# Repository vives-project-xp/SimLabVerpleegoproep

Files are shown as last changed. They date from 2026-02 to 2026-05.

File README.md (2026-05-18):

# SimLab Verpleegoproepsysteem

## Projectbeschrijving

Het doel van dit project is om een systeem te ontwikkelen die hulpverlenend personeel help om visueel te zien welke patiënten zorg nodig hebben en waar collega’s al bezig zijn. Het systeem werkt met drukknoppen en signalisatie lampen zodat de status van de kamer kan weergegeven worden. Wanneer de patiënt urgente hulp nodig geeft, krijg het personeel hiervan ook een melding op hun telefoon.

Dit project zal dan ook werkelijk gebruikt worden door de graduaat en bachelor opleidingen verpleegkunde als lesmateriaal.

## Functies/onderdelen

- **Drukknop aan bed:** gebruikt door patiënt om hulp op te roepen.
- **Drukknop aan muur:** gebruikt door hulpverlener om aanwezigheid te registreren en lamp uit te schakelen.
- **Signaallamp aan muur of deur:** geeft visueel de status van de kamer weer.
- **Telefoon hulpverlener:** krijgt melding wanneer hulp urgent is.

## Optionele uitbreidingen
Dit zijn uitbreidingen die mogelijk zijn als we genoeg tijd over hebben, de basis functionaliteiten moeten eerst werkend zijn.

- **Applicatie met status:** kan gebruikt worden om weer te geven welke status de geregistreerde kamers hebben.
- **Batterij status:** de status van de batterij wordt weergegeven op een applicatie, op deze manier weten we wanneer de batterij moet opgeladen worden.

## Affiches

### Begin affiche

<div style="display: flex; gap: 10px;">
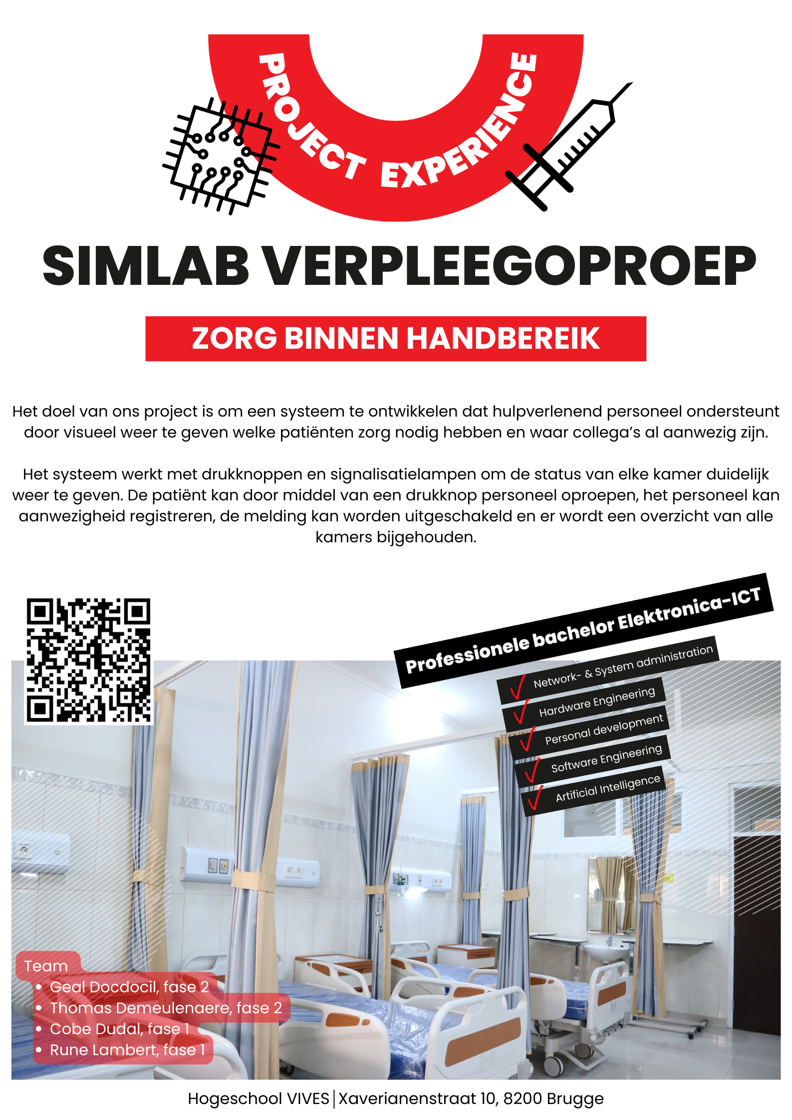
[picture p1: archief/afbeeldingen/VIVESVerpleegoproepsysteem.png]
   
</div>

### Eind affiche

<div style="display: flex; gap: 10px;">
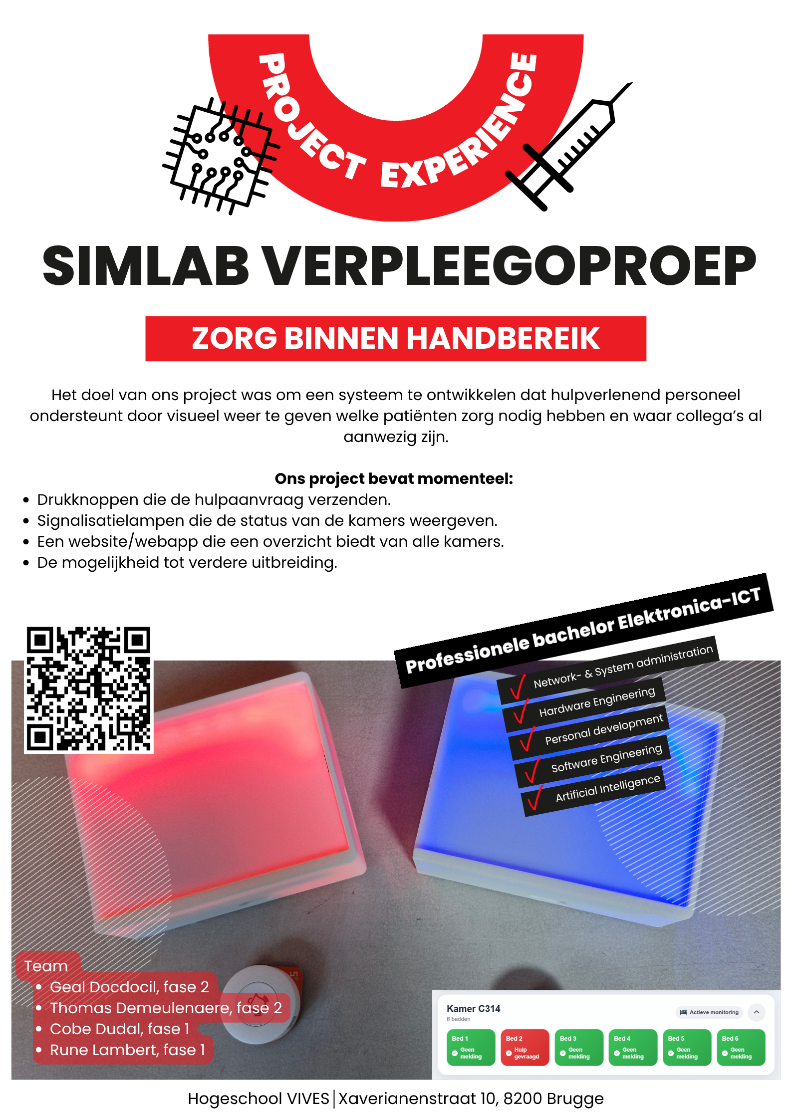
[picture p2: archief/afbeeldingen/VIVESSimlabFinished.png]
   
</div>

## Folder structuur
- [Hardware](./hardware/readme.md) : Hier bevind alles te maken met de hardware.
- [Software](./software/readme.md ) : Hier bevind alles te maken met de software.
- [Archief](./archief/readme.md) : Hier vindt u moglijke ideeën en bestanden die gebruikt worden in de documentatie.
- [Research](./Research/readme.md) : Hier vindt u het onderzoek in verband met het project.

## Team
- [Foto Thomas Demeulenaere, fase 2](https://github.com/Thomas8650)

- [Foto Geal Docdocil, fase 2](https://github.com/Gdoc141)

- [Foto Cobe Dudal, fase 1](https://github.com/ToneyBacon)

- [Foto Rune Lambert, fase 1](https://github.com/RuneLambert)

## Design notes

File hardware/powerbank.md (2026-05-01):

# **Specificaties en gegevens powerbank**

# Inleiding

In dit bestand zullen de specificaties en gegevens van de powerbank terug te vinden zijn.

## Gegevens

| Soortnaam | Laaduitgangen en -schachten |  Capaciteit (mAh, Ah) | Laadstroom (max.) | Technologie |
|--|--|--|--|--|
| Powerbank | 2 | 10000 mAh | 3100 mA | LiPo |

| Lengte | Breedte | Hoogte | Gewicht |
|--|--|--|--|
| 91 mm | 63 mm| 22 mm| 182 g|

| Kleur (specifiek) | Draadloos oplaadbaar | Afm. |
|--|--|--|
| Zwart | Nee| (l x b x h) 91 x 63 x 22 mm|

| Aansluitingen | 1x USB-C | Kenmerken powerbank |
|--|--|--|
| 1x USB-A | 1x USB-micro| Statusweergave|

| USB-C uitgangsspanning (max.) | USB-C uitgangsstroom (max.) | USB-C ingangsspanning (max.) | USB-C ingangsstroom (max.) | Grootte |
|--|--|--|--|--|
| 5 V| 3.1 A| 5 V| 2.4 A| AAA (potlood)|

## Duur bij max. belasting

Uit de gegevens van de powerbank kunnen we afleiden hoelang deze kan gebruikt worden met een max. belasting.
We kunnen afleiden dat een volledig opgeladen powerbank voor ongeveer 53,8 min een volle belasting van 5 V en 3,1 A kan voorzien.

In realiteit zal de powerbank nooit deze grote waarden moeten leveren en voor een constante periode. De powerbank zal niet altijd aan zijn. Indien deze toch aan is zullen de LED's niet altijd branden en de getrokken stroom nooit 3,1 A bereiken.

Dit betekend dat de daadwerkelijke levensduur van een volledig opgeladen powerbank stukken groter zal zijn dan deze 53,8 min.

Als we een ruim gerekende stroom van ongeveer 500 mA nemen, resulteerd dit in een levensduur van ongeveer 20 h. Deze 20 h is dan ook voor constante belasting, in realiteit zullen de LED's niet altijd aan liggen en ook niet met volle sterkte branden. Als we met een factor 3 (LED's branden niet altijd en worden niet altijd gebruikt) rekening houden hebben we een levensduur van 60 h, deze waarde kan in realiteit nog hoger liggen aangezien de gebruikte waarden nog altijd ruim gerekend zijn.

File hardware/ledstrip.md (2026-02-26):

# Informatie LED strip

## Belangrijke gegevens

**Naam:** PN.:HC-F5V-60L-60LED-W-WS2812B

**Lengte:** 1 meter

**Werk spanning:** DC5V

**Max. vermogen:** 9W

**Verpakking:** Bare Board

**Werkmodus:** external controller

## Aansluitingen
**JST-SM stekker (3-pin):** 
 - Rood: VCC
 - Wit: GND
 - Groen: DAT

**2 apparte kabels:** 
 - Rood: +5V
- Zwart: GND

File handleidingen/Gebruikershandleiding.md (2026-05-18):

# Gebruikershandleiding

## Inhoudstafel 
[**Inleiding**](#inleiding)<br>
[**Installatie systemen**](#installatie)<br>
- [**Installatie knop**](#knop)<br>
- [**Installatie applicatie**](#applicatie)<br>

[**Gebruik knop**](#gebruik-knop)<br>
[**Gebruik app/website**](#gebruik-app_website)<br>
[**Gebruik signalisatie lamp**](#gebruik-signalisatie-lamp)<br>
[**Onderhoud lamp en knop**](#onderhoud)<br>
[**FAQ**](#faq)<br>

## Inleiding
Dit bestand bevat een uitgebreide handleiding bestemd voor de gebruiker van het systeem, er zullen geen technische details of diepgang voorkomen. Er zal gesproken worden over de installatie, gebruik, onderhoud en FAQ.

## Installatie
### **Knop**
De knop installeren gebeurt heel eenvoudig.
1.	Steek de knophouder in het gat van de oranje schijf.

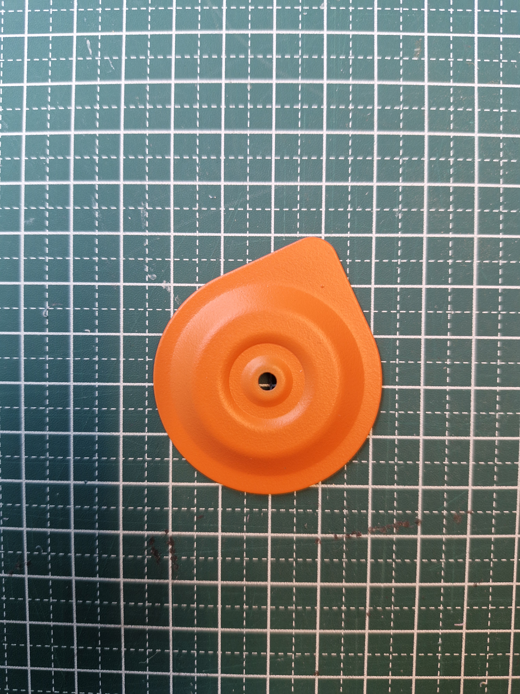
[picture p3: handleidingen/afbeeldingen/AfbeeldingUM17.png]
<br>

2.	Klik de knop op de schijf met behulp van de ingebouwde magneet.
3.	Schuif de knophouder over de afstandsbediening van het bed of over andere passende objecten, er kan ook gebruik gemaakt worden van een koord.
4.	De knop zou standaard al in het systeem moeten zitten waardoor deze meteen bruikbaar zou moeten zijn, indien dit niet gebeurt druk dan kort op de kleine pairing knop aan de zijkant van de knop zelf.

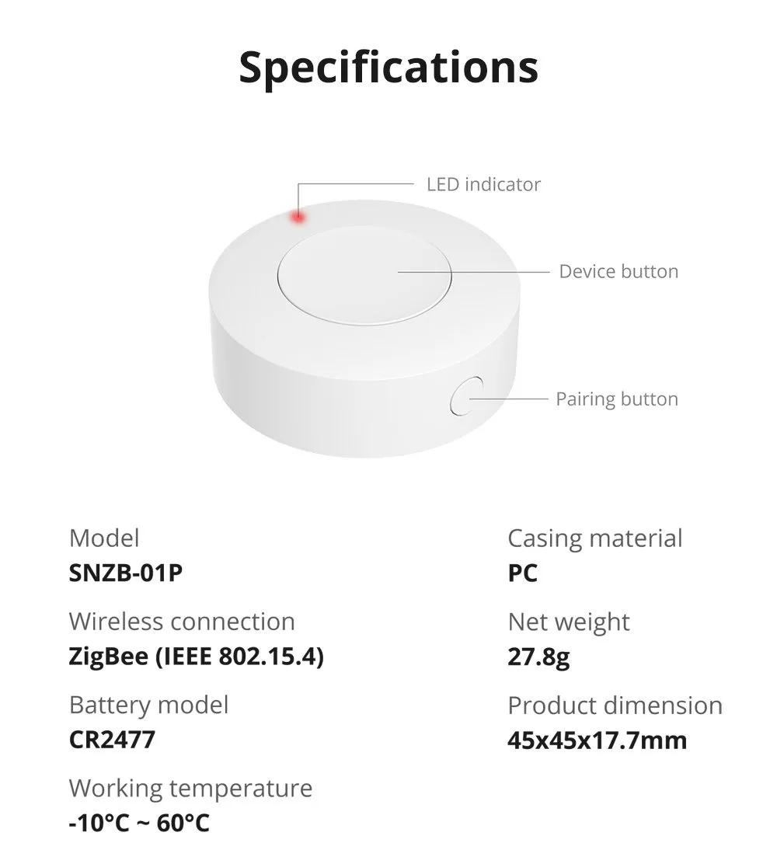
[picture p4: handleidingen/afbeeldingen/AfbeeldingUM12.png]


### **Applicatie**
De volledige installatiehandleiding voor de applicatie (voor zowel iPhone als Android) is terug te vinden in de [PWA-Installatiehandleiding](PWA-Installatiehandleiding.md).

## Gebruik knop
Bij iedere melding of verandering in de app, krijgt iedere medewerker (docent en student) die op dat moment zijn ingelogd en meldingen ingeschakeld heeft een bijhorende melding.

### **Meldingen patiënt**
#### **Hulp gevraagd**
Wanneer de patiënt hulp nodig heeft drukt deze **1x kort** op de knop.

Dit zorgt ervoor dat het bijhorende bed op de app rood kleurt, deze als “Hulp gevraagd” geregistreerd wordt en indien er geen belangrijkere meldingen zijn zal de lamp van de kamer rood kleuren.

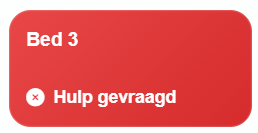
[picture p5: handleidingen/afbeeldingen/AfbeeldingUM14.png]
<br>

### **Personeel (medewerker)**
#### **Aanwezigheid registreren**
Als de medewerker aanwezigheid wilt registreren wanneer er voordien hulp gevraagd werd, kan dit door **2x kort na elkaar** op de knop te drukken waar de melding vandaan kwam.

Dit zorgt ervoor dat het bijhorende bed op de app van rood naar oranje kleuren, deze als “Collega aanwezig” geregistreerd wordt en indien er geen belangrijkere meldingen zijn zal de lamp van de kamer oranje kleuren.

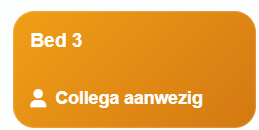
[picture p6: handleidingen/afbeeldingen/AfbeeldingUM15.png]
<br>

#### **Uitschakelen**
Als de medewerker de melding wilt afhandelen of uitschakelen kan dit door **1x kort** op de bijhorende knop te drukken (enkel als deze al brand anders wordt er om hulp gevraagd).

Hierdoor zal het bijhorende bed op de app terug groen kleuren en de lamp van de bijhorende kamer uitgeschakeld worden indien er geen andere meldingen zijn.

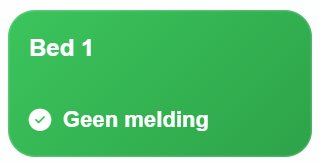
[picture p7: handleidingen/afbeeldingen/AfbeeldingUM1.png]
<br>

#### **Extra hulp nodig**
Als de medewerker **1x lang** de knop indrukt (ongeveer 2s-3s), zal er een extra hulp aanvraag verzonden worden.
Ook als er meer dan één "Hulp gevraagd" meldingen in dezelfde een kamer zijn zal automatisch extra hulp opgeroepen worden.

Dit zorgt ervoor dat het bijhorende bed op de app blauw brand, deze als “Extra hulp nodig” geregistreerd wordt en de lamp van de bijhorende kamer blauw kleurt.

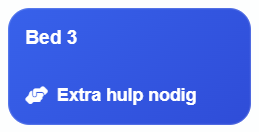
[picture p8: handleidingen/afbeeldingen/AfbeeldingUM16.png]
<br>

**Instructieblad:**

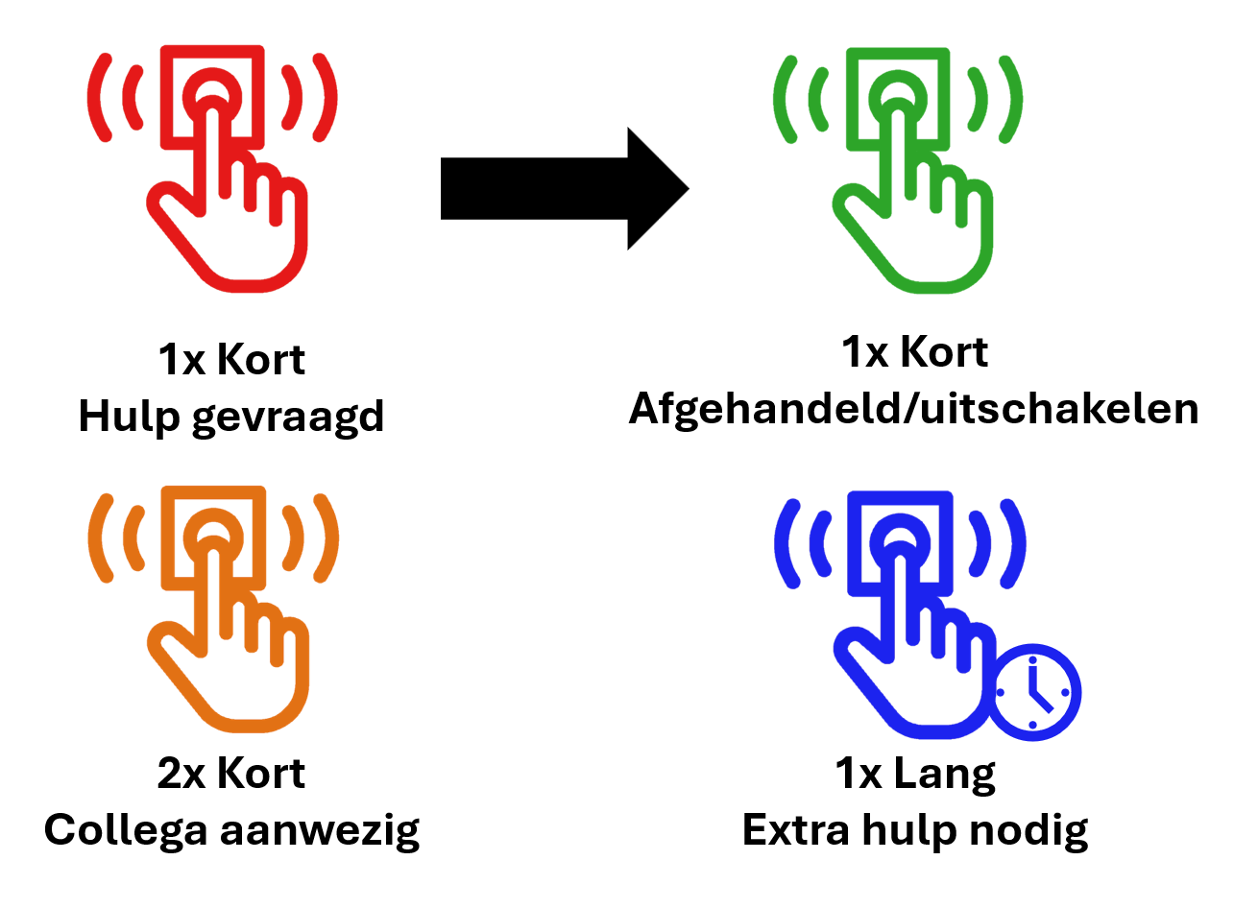
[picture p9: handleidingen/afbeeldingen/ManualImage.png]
<br>

## Gebruik app_website
Bij ons systeem hoort een website en een app die een overzicht geven van de meldingen, status van kamers met bedden en het mogelijk maakt om meldingen te ontvangen.
Bij iedere melding of verandering in de app, krijgt iedere medewerker (docent en student) die op dat moment zijn ingelogd een bijhorende melding.
### **Inloggen**
Als u surft naar https://verpleegkunde.voltlab.net of de applicatie opent komt u op onderstaand scherm terecht.
 
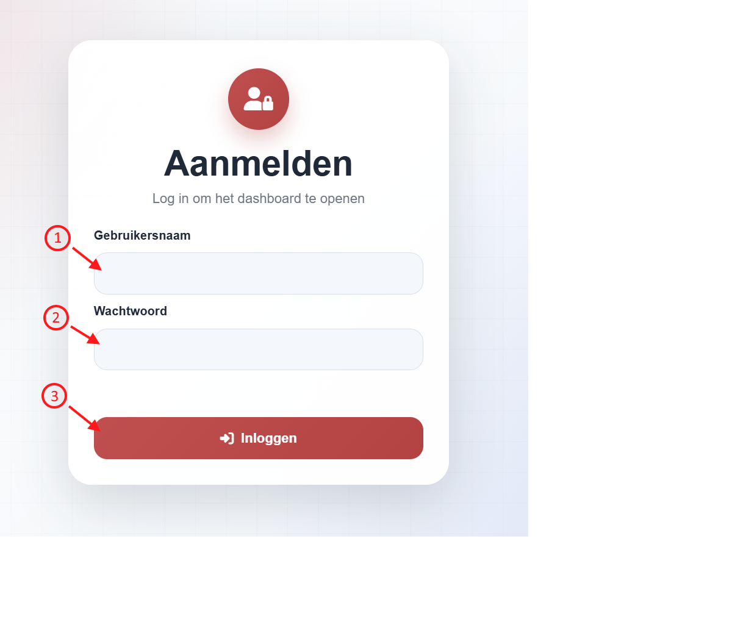
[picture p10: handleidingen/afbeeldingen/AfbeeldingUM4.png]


1.  In het vak “Gebruikersnaam” vult u een bestaande gebruikersnaam in. Indien u een leerling bent vult u “Leerling” in, indien u een leerkracht bent vult u “Leerkracht” in.

2.  In het vak “Wachtwoord” vult u een correct wachtwoord in. Indien u een leerling bent krijgt u deze van uw leerkracht.

3.  Wanneer alles ingevuld is mag op de “Inloggen” knop gedrukt worden.<br>
**OPGELET: Het inloggen is hoofdletter gevoelig.**

### **Overzicht (leerling)**
Wanneer u ingelogd bent als leerling krijgt u onderstaand overzicht.

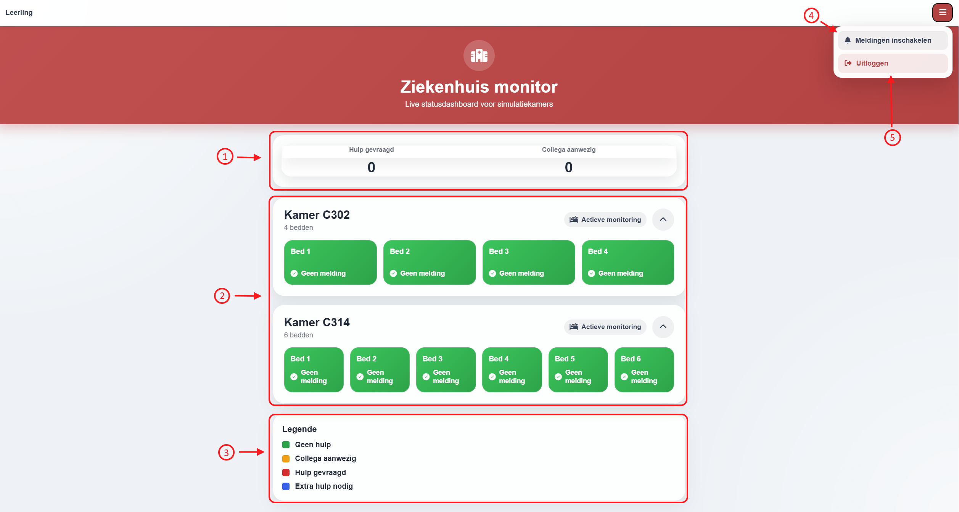
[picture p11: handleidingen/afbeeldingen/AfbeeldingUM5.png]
<br>
 
1.  **Overzicht aanvragen:** Hier is de totale som van alle aanvragen te zien. De hoeveelheid “Hulp gevraagd” en “Collega aanwezig” meldingen zijn hier terug te vinden.

2.  **Overzicht kamers:** Hier is een overzichtelijke weergave van de kamers terug te vinden. Per kamer en per bed zijn er vakken voorzien, deze veranderen van kleur en melding afhankelijk van het gebruik van de bijhorende knop. Op deze manier is alles makkelijk bij te houden.

3.  **Legende:** Een kleuren legende met informatie over de meldingen.

4.  **Meldingen inschakelen:** Deze knop moet ingedrukt worden om notificaties op een telefoon of andere toestellen te kunnen ontvangen.<br>
**OPGELET: Het is enkel mogelijk om notificaties te ontvangen met de applicatie niet met de website.**

1.  **Uitloggen:** Met deze knop kunt u uitloggen, na het uitloggen ontvangt u geen meldingen meer.

### **Overzicht (leerkracht)**
Het overzicht van een leerkracht is gelijkaardig aan dat van een leerling. Een leerkracht ziet wel de knop “Instellingen” staan onder de “Meldingen inschakelen” knop. Wanneer deze wordt ingedrukt komt u op het onderstaande menu terecht.

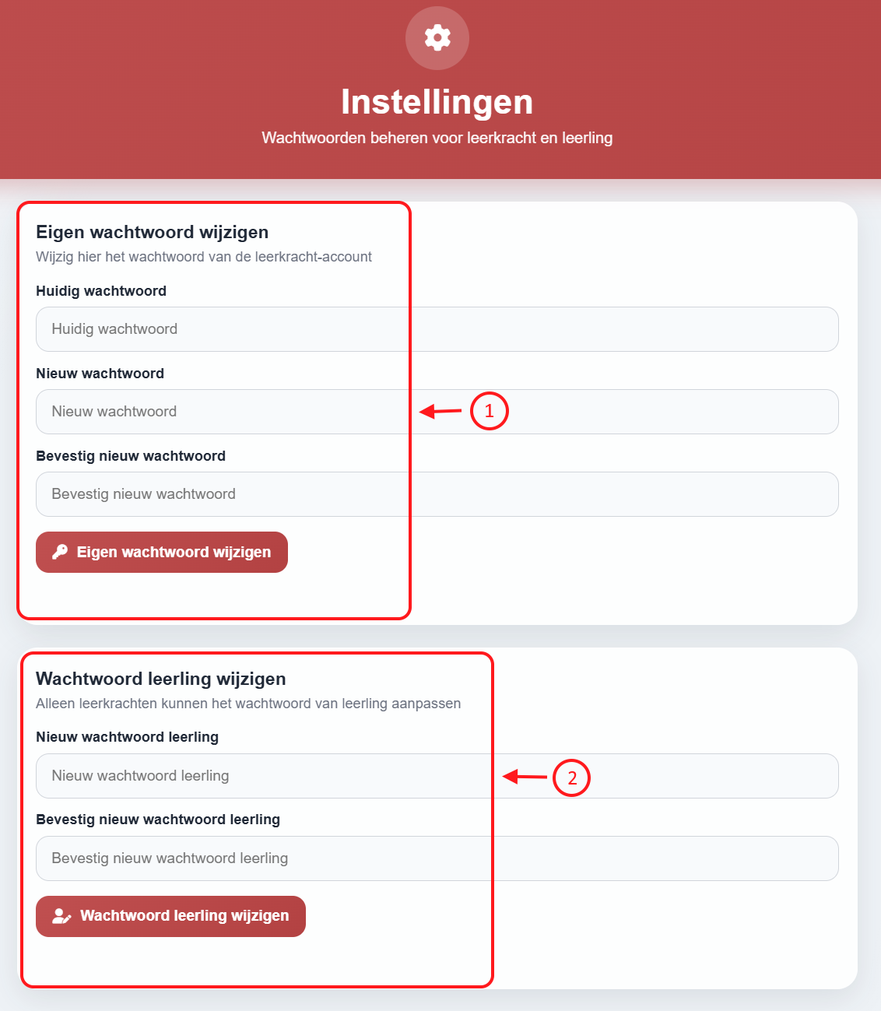
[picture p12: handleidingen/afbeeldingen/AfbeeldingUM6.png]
<br>
 
1.  In deze vakken kunt u het algemeen wachtwoord voor het leerkrachten account aanpassen. Dit gebeurt door eerst het huidige wachtwoord in te vullen en daarna twee keer het nieuwe wachtwoord.

2.  In deze vakken kunt u het algemeen wachtwoord voor het leerlingen account aanpassen. Dit gebeurt door twee keer het nieuwe wachtwoord in te vullen.<br>
**OPGELET: De wachtwoorden zijn hoofdletter gevoelig.**

## Gebruik signalisatie lamp  

### **Aanschakelen**
Het aanschakelen van de lamp gebeurt door 1x te drukken op de power knop van de powerbank. Deze knop kan eenvoudig bereikt worden door het gat in de behuizing.
Na het inschakelen zal de lamp voor 3s groen branden, dit betekend dat de lamp correct is ingeschakeld. Indien u niet zeker bent of de batterij ingeschakeld is, kunt u altijd het deksel er vanaf schuiven en controleren of de lichtjes van de powerbank effectief aan zijn.<br>
 
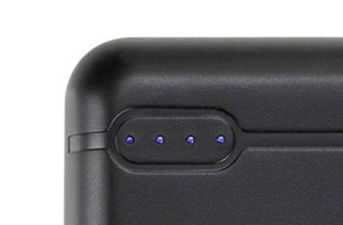
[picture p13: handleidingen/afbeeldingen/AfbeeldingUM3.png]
 

### **Uitschakelen**
Het uitschakelen van de lamp gebeurt door 2x kort achtereenvolgens op de power knop van de powerbank te drukken.

Wanneer de lamp geen veranderingen ontvangt voor een uur lang, zullen de batterij en lamp zich vanzelf uitschakelen.

Indien u niet zeker bent of de lamp ingeschakeld is, kunt u ook weer het deksel er vanaf schuiven en controleren of de lichtjes van de powerbank effectief uit zijn.<br>
 
 

## Onderhoud
### **Lamp**
Aangezien de lampen werken met een powerbank, moeten deze tijdig herladen worden.

1.  Verwijder de behuizing van de muur.

2.  Verwijder het schuivende deksel van de behuizing, nu zou de powerbank zichtbaar moeten zijn.

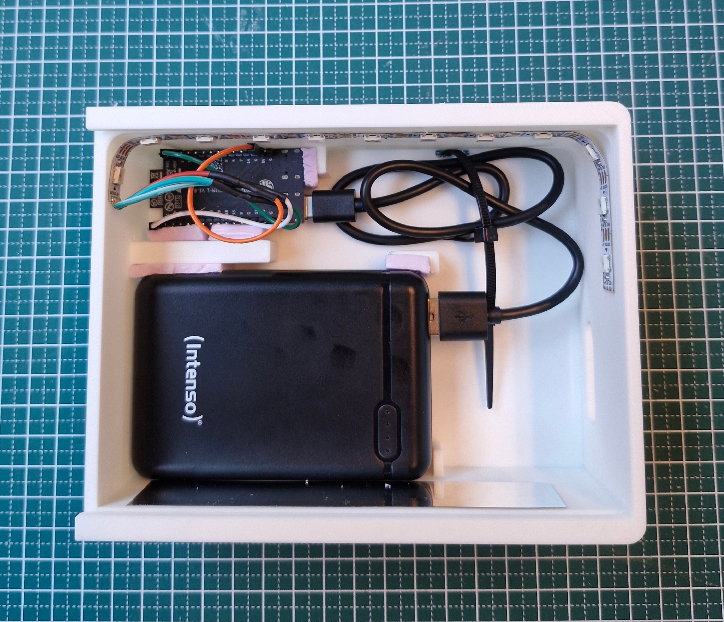
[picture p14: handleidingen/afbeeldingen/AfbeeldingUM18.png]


3.  Gebruik een USB-C kabel en steek deze in de correcte poort aangeduid op de powerbank als “USB-C In/Out”.

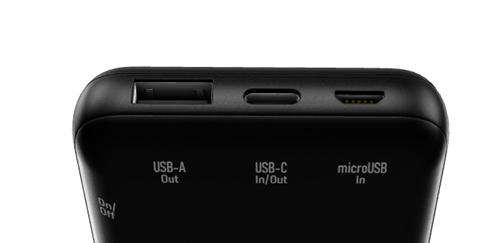
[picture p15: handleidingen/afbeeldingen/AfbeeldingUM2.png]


4.  Deze kabel kan nu gebruikt worden om de powerbank op te laden. U kunt de kabel makkelijker bereikbaar maken door deze door het voorziene gat in de behuizing te steken of u kunt gerust de powerbank uit de behuizing halen.

    **OPGELET: Voor het uithalen van de powerbank zijn er een aantal belangrijke handelingen nodig die behandelt worden vanaf stap 8**. 

5.  De status van het opladen kan gezien worden aan de bovenzijde van de powerbank.
 
 

6.  Als de powerbank klaar is met opladen, kunt u de kabel terug verwijderen van de poort.
   
7.  Vervolgens mag de behuizing terug gesloten worden en opgehangen worden.

8.  Als u de powerbank wilt verwijderen van de behuizing moet u eerst de al aangesloten kabel verwijderen. Deze kabel zou moeten in de “Output-A” poort moeten zitten.

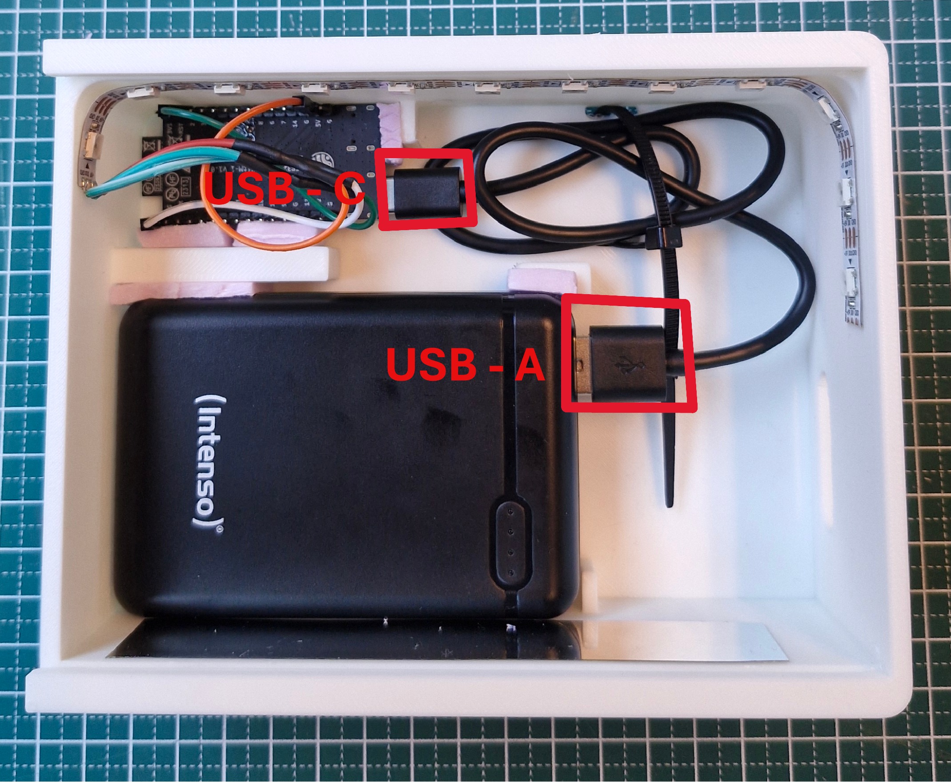
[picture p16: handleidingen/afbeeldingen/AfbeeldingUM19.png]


9.  Vervolgens mag de powerbank uit het vak van de behuizing gehaald worden.

10. Nu kunt u deze apart opladen.

11. Wanneer deze voldoende is opgeladen kunt u deze terug steken in het daarvoor bedoelde vak in de behuizing.

12. Vervolgens mag de kabel terug in de “Output-A” poort van de powerbank gestoken worden.

    **OPGELET: Let er op dat de powerknop van de powerbank (rechter zijde) opnieuw ingedrukt is voor gebruik.**

13. Nu mag de behuizing terug gesloten en opgehangen worden.

### **Knop**
Aangezien de knoppen op een batterij werken, moeten deze tijdig vervangen worden.<br>
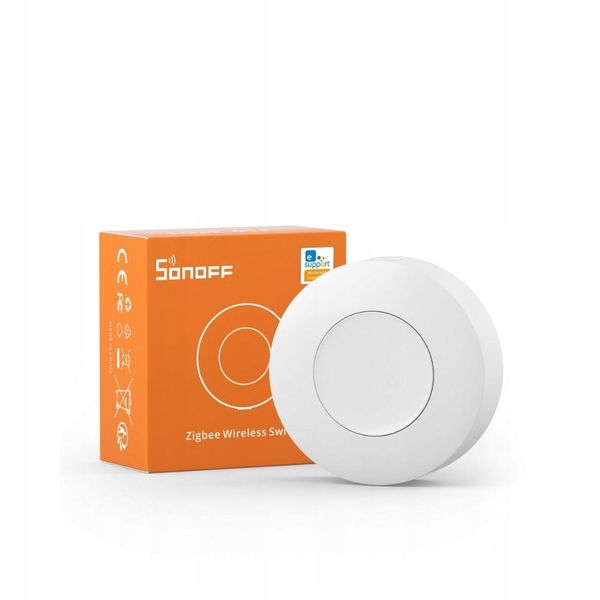
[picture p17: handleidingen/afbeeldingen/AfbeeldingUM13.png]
<br>

1.  Haal de knop van de oranje magneet af.

2.  Aan de achterkant van de knop zit een gleuf.

3.  Gebruik een muntstuk of gelijkaardige voorwerpen om in de draairichting aangeduid door de pijl te draaien.

4.  Wanneer het deksel van de knop is kunt u de wegwerpbare batterij vervangen.

5.  Wanneer dit gebeurt is kunt u het deksel terug op de knop vast draaien.

6.  Vervolgens mag de knop terug aan de oranje magneet gehangen worden en is het klaar voor gebruik.

## FAQ
Q: De signalisatielamp werkt niet meer.
<br>
A: 
 - Controleer of de kabel van de powerbank naar de microcontroller correct is aangesloten. De kabel moet van de “Output-A” poort van de powerbank naar de “USB” poort van de microcontroller gaan.
<br>



Q: De knop reageert niet op de ledstrip en de website.
<br>
A:
- Als de knop heeft uitgestaan en dezen niet meer reageert, moet u op het kleine knopje drukken aan de zijkant op van de knop (pairing button). Als u vervolgens opnieuw probeert, zou het systeem moeten reageren.<br>

<br>

Q: Ik kan niet inloggen.
<br>
A: 
 - Controleer of u de gebruikersnaam en wachtwoord volledig correct ingeeft. Deze zijn hoofdlettergevoelig en spaties worden ook als verkeerd gezien.
<br>

Q: Ik krijg geen meldingen meer.
<br>
A: 
 - Een gebruiker kan enkel meldingen ontvangen als deze de applicatie geïnstalleerd heeft. In de applicatie zelf moet de "Meldingen inschakelen" knop zeker ingedrukt worden, wanneer deze ingedrukt is moet er op "Meldingen toestaan" gedrukt worden zodat de applicatie toestemming krijgt om meldingen te verzenden. <br> Indien deze oplossingen niet hielpen, kunt u altijd de applicatie opnieuw installeren.
<br>

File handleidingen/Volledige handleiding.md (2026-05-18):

# Handleiding

## Inhoudstafel 
[**HomeAssistant installeren op Raspberry Pi**](#homeassistant-installeren-op-raspberry-pi)

[**Code toevoegen op Esp32**](#code-toevoegen-op-esp32)

[**yamle code in home assitant**](#yamle-code-in-home-assitant)

[**Nieuw bed of kamer toevoegen aan de website**](#nieuw-bed-of-kamer-toevoegen-aan-de-website)

## HomeAssistant installeren op Raspberry Pi
### Inhoud

In dit onderdeel zal stap voor stap uitgelegd worden hoe wij HomeAssistant op een Raspberry Pi hebben gezet.

### Benodigdheden

- Raspberry Pi (wij gebruikten versie 5)

- Power supply

- Micro SD card (min. 32 GB)

- SD card lezer

- Ethernet kabel

- Laptop

### Uitvoering

#### Installeren op Raspberry Pi

1. Als de Raspberry Pi Imager nog niet geïnstalleerd is, download en installeer deze dan op uw computer zoals beschreven onder [https://www.raspberrypi.com/software/](https://www.raspberrypi.com/software/).

2. Onder device selecteer het toestel die u zal gebruiken (in ons geval versie 5).
   <div style="display: flex; gap: 10px;">
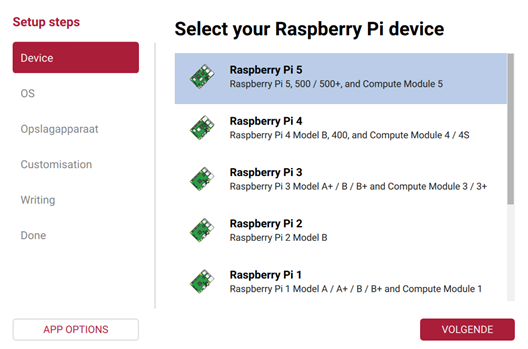
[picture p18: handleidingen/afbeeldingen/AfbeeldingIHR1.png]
   
</div>

3. Klik daarna op volgende.
   <div style="display: flex; gap: 10px;">
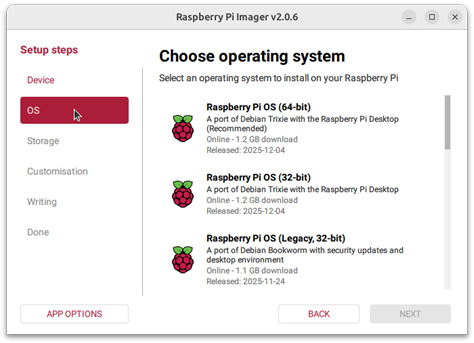
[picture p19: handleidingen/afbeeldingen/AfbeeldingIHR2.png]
   
</div>

4. Selecteer **Other specific-purpose OS** > **Home automation** > **Home Assistant**.
   <div style="display: flex; gap: 10px;">
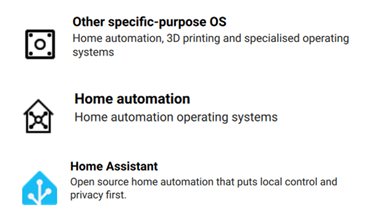
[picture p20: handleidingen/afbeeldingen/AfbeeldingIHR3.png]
   
</div>

5. Kies het Home Assistant-besturingssysteem dat overeenkomt met het gebruikte hardware (voor ons RPi 5).

6. Kies de opslagplaats:

- Plaats de SD-kaart in de computer. Wees zeker dat de inhoud weg mag want de **inhoud** van de kaart wordt **overschreven**.

- Selecteer uw SD-kaart.
  <div style="display: flex; gap: 10px;">
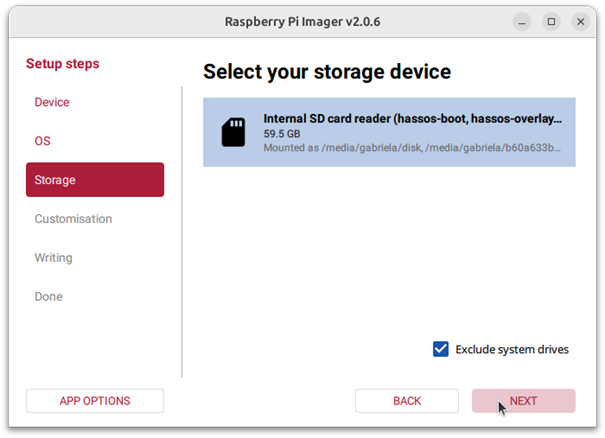
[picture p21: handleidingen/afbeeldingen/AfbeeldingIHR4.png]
   
</div>

7. Schrijf het installatieprogramma naar de SD-kaart:

- Om het proces te starten, selecteert u **Volgende** en vervolgens **Schrijven**.

- Wacht tot het Home Assistant OS naar de SD-kaart is geschreven.
  <div style="display: flex; gap: 10px;">
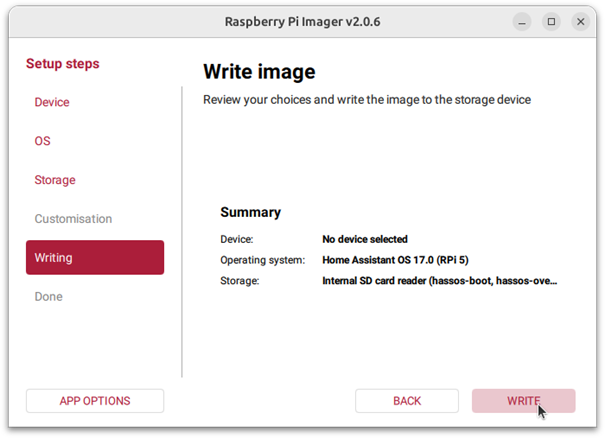
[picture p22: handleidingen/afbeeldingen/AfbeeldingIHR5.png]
   
</div>

8. Selecteer **Finish** en werp de SD kaart uit.

#### Opstarten Raspberry Pi

- Plaats de SD-kaart in uw Raspberry Pi.

- Sluit een ethernetkabel aan en zorg ervoor dat de Raspberry Pi is aangesloten op hetzelfde netwerk als uw computer en verbinding heeft met internet.

- Sluit de voeding aan om het apparaat op te starten.

#### Toegang tot HomeAssistant

Binnen enkele minuten na het aansluiten van de Raspberry Pi kunt kan het nieuwe Home Assistant bereikt worden.

Er zijn 2 manieren om op de pagina te geraken.

1. Voer in de browser van uw desktopsysteem [homeassistant.local:8123](http://homeassistant.local:8123/) in.

	Op deze manier kan je echter op een verkeerde pagina terecht komen (van een ander toestel).

2. Om zeker te zijn dat de juiste pagina wordt bereikt vul dan http://X.X.X.X:8123 (vervang X.X.X.X door het IP-adres van je Raspberry Pi) in een browser.

Om het IP-adres van je Raspberry Pi uit te lezen gebruik je een HDMI kabel en verbind u deze met de Raspberry Pi en een monitor. Na een aantal seconden zou de console output van de Raspberry Pi zichtbaar moeten worden. Hierbij staat ook het IP-adres.

**Bronnen:**

Handleiding

[Raspberry Pi - Home Assistant](https://www.home-assistant.io/installation/raspberrypi/)

## Code toevoegen op Esp32

Om de code te zetten moet je eerst in arduino ide de juiste code file openen namelijk deze: [code ledstrip](/software/ledProgramma's/ledstrip/ledstrip.ino). Eenmaal je deze code hebt geselecteerd moet je nog een paar instellingen in arduino ide instellen zodat je apparaat zeker als een een zigbee aparaat werkt. Dit vind je in deze file: [instellingen arduino](/software/ledProgramma's/arduino_instellingen.md)

## yamle code in home assitant
De yaml code's zijn puur voor in de automatiseringen te plaatsen hoe je een eerste automatisering aanmaaken en ook nog helpers de info hierover  bevind zich in deze file: [automatisering aanmaken](/software/Homa%20assistant/Helpers%20en%20Automatisering%20.md). Eenmaal je dit hebt gedaan kun je ze plakken in de juiste automatiseringen en ben je klaar met de automatisering van knop naar ledstrip. 

## Nieuw bed of kamer toevoegen aan de website

Als je een nieuwe knop/bed of een volledig nieuwe kamer wilt zichtbaar maken op de website, moet je drie dingen aanpassen: de HTML-pagina, het databestand op de server en (optioneel) Home Assistant. Het JavaScript-bestand `script.js` hoef je **nooit** aan te passen — dat werkt automatisch met alle bed-IDs die de backend teruggeeft.

### Situatie 1: Extra bed toevoegen aan een bestaande kamer

Voorbeeld: een 5e bed toevoegen aan kamer C302.

#### Stap 1 — `frontend/index.html`

Zoek het blok van de kamer. Dat ziet er zo uit:

```html
<article class="card room-card">
    <div class="card-top">
        <div>
            <p class="room-name">Kamer C302</p>
            <p class="room-subtitle">4 bedden</p>   <!-- ← pas dit getal aan -->
        </div>
        ...
    </div>

    <div id="bedsC302" class="bed-grid">
        <!-- bestaande bedden staan hier -->

        <!-- voeg dit blok toe voor het nieuwe bed: -->
        <div class="bed free" id="C302_5">
            <div class="bed-label">Bed 5</div>
            <div class="bed-status">
                <i class="fa-solid fa-circle-check"></i>
                <span>Geen melding</span>
            </div>
        </div>

    </div>
</article>
```

Pas ook de subtitel aan: `4 bedden` → `5 bedden`.

Het `id`-attribuut van het nieuwe `<div>`-blok moet exact overeenkomen met de naam die je in stap 2 gebruikt: `C302_5`.

#### Stap 2 — `backend/data/rooms.json` (op de VM)

Open het bestand `rooms.json` en voeg het nieuwe bed toe:

```json
{
  "beds": {
    "C302_1": "idle",
    "C302_2": "idle",
    "C302_3": "idle",
    "C302_4": "idle",
    "C302_5": "idle",   ← nieuw
    "C314_1": "idle",
    ...
  }
}
```

Sla het bestand op. De server hoeft niet herstart te worden.

#### Stap 3 — Home Assistant

Volg de stappen in [Helpers en Automatisering](/software/Home%20assistant/Helpers%20en%20Automatisering%20.md) om een nieuwe `input_select` helper aan te maken voor het nieuwe bed (bijv. `input_select.bed5_c302`) en koppel de bijbehorende knop eraan via een automatisering.

---

### Situatie 2: Volledig nieuwe kamer toevoegen

Voorbeeld: kamer C320 toevoegen met 3 bedden.

#### Stap 1 — `frontend/index.html`

Voeg een nieuw `<article>`-blok toe binnen `<section class="card-container">`, na de bestaande kamers:

```html
<article class="card room-card">
    <div class="card-top">
        <div>
            <p class="room-name">Kamer C320</p>
            <p class="room-subtitle">3 bedden</p>
        </div>
        <div class="room-badge">
            <i class="fa-solid fa-bed-pulse"></i>
            <span>Actieve monitoring</span>
        </div>
    </div>

    <div id="bedsC320" class="bed-grid">
        <div class="bed free" id="C320_1">
            <div class="bed-label">Bed 1</div>
            <div class="bed-status">
                <i class="fa-solid fa-circle-check"></i>
                <span>Geen melding</span>
            </div>
        </div>

        <div class="bed free" id="C320_2">
            <div class="bed-label">Bed 2</div>
            <div class="bed-status">
                <i class="fa-solid fa-circle-check"></i>
                <span>Geen melding</span>
            </div>
        </div>

        <div class="bed free" id="C320_3">
            <div class="bed-label">Bed 3</div>
            <div class="bed-status">
                <i class="fa-solid fa-circle-check"></i>
                <span>Geen melding</span>
            </div>
        </div>
    </div>
</article>
```

#### Stap 2 — `backend/data/rooms.json` (op de VM)

Voeg alle bedden van de nieuwe kamer toe:

```json
{
  "beds": {
    "C302_1": "idle",
    ...
    "C320_1": "idle",   ← nieuw
    "C320_2": "idle",   ← nieuw
    "C320_3": "idle"    ← nieuw
  }
}
```

#### Stap 3 — Home Assistant

Maak voor elk nieuw bed een `input_select` helper aan en koppel de bijbehorende knop via een automatisering. Zie [Helpers en Automatisering](/software/Home%20assistant/Helpers%20en%20Automatisering%20.md) en [MQTT en apparaten toevoegen](/software/Home%20assistant/MQTT%20en%20apparaten%20toevoegen.md).

---

### Naamgeving — belangrijk

De ID die je gebruikt in de HTML (`id="C302_5"`) moet exact hetzelfde zijn als:

- de sleutel in `rooms.json` (`"C302_5": "idle"`);
- de `bedId` die Home Assistant verstuurt naar de website via `POST /api/call`.

Als één van de drie niet overeenkomt, zal de statuskleur op de website niet bijwerken.

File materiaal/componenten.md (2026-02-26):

# Benodigheden

## Dit is voor 1 bed in 1 kamer

- 1x [rapsberrypi 4 of 5](https://www.conrad.be/nl/p/raspberry-pi-5-b-4-gb-4-x-2-4-ghz-raspberry-pi-2980039.html)
- 1x [SD-kaart](https://www.conrad.be/nl/p/intenso-3411480-sdhc-kaart-32-gb-class-10-417610.html)
- 1x [usb voedingskabel met adapter](https://www.tinytronics.nl/nl/power/voedingen/5v/raspberry-pi-usb-c-voeding-5.1v-3a-zwart)
- 1x [zigbee dongle](https://opencircuit.be/product/sonoff-zigbee-3.0-usb-dongle-plus-zbdongle-e)
- 1x [ledstrip](https://www.tinytronics.nl/nl/verlichting/led-strips/led-strips/ws2812b-digitale-5050-rgb-led-strip-60-leds-1m)
- 1x [Esp32 C6 met zigbee](https://www.conrad.be/nl/p/espressif-esp32-c6-devkitm-1-n4-developmentboard-2992163.html#productTechData)
- 1x [usb c kabel naar usb a voor voeding esp](https://www.allekabels.be/usb-c-kabel/11518/2259587/usb-c-naar-usb-a-kabel.html?lang=nl-be)
- 1x [sonoff drukknop](https://www.tinytronics.nl/nl/platformen-en-systemen/sonoff/zigbee/sonoff-snzb-01p-draadloze-schakelaar-zigbee )
- 1x [zigbee tuya switch]()
- 1x [powerbank](https://www.conrad.be/nl/p/intenso-xs10000-powerbank-10000-mah-lipo-zwart-statusweergave-2179961.html)

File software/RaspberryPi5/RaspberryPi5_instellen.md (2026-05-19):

# Raspberry Pi 5 configuratie voor Zigbee2MQTT

Deze documentatie beschrijft wat er op de Raspberry Pi 5 werd geïnstalleerd en aangepast om Zigbee-apparaten via Zigbee2MQTT te kunnen gebruiken in Home Assistant.

---

## 1. Doel van de Raspberry Pi

De Raspberry Pi 5 wordt gebruikt als Zigbee gateway.

De Pi doet het volgende:

* leest Zigbee-apparaten uit via de SONOFF Zigbee USB dongle
* draait Zigbee2MQTT in Docker
* stuurt Zigbee-data door naar de MQTT broker
* Home Assistant leest daarna deze MQTT-data uit

Schema:

```text
Zigbee apparaat
        ↓
SONOFF Zigbee USB dongle
        ↓
Raspberry Pi 5
        ↓
Zigbee2MQTT
        ↓
MQTT broker
        ↓
Home Assistant
```

---

## 2. Besturingssysteem

Op de Raspberry Pi werd geïnstalleerd:

```text
Raspberry Pi OS 64-bit
```

Raspberry Pi OS Lite was ook mogelijk, maar de gewone 64-bit versie werkt ook.

---

## 3. Gebruiker op de Pi

Gebruiker:

```text
<username>
```

Wachtwoord:

```text
<password>
```

SSH gebruiken:

```bash
ssh <username>@<ip-van-de-pi>
```

---

## 4. Netwerkgegevens Raspberry Pi

Ethernet MAC-adres:

```text
<ethernet-mac>
```

Wi-Fi MAC-adres:

```text
<wifi-mac>
```

Deze MAC-adressen kunnen gebruikt worden om een vast IP-adres te reserveren via DHCP.

IP-adres controleren:

```bash
hostname -I
```

`hostname -I` toont meerdere IP-adressen.  
Het relevante LAN IP is:

```text
<ip-van-de-pi>
```

Actieve wifi controleren:

```bash
iwgetid
```

Netwerkinterfaces bekijken:

```bash
ip link
```

---

## 5. Systeem updaten

Na installatie werd het systeem geüpdatet:

```bash
sudo apt update
sudo apt full-upgrade -y
sudo reboot
```

---

## 6. Docker installeren

Zigbee2MQTT draait in Docker.

Docker werd geïnstalleerd met:

```bash
curl -fsSL https://get.docker.com -o get-docker.sh
sudo sh get-docker.sh
sudo usermod -aG docker $USER
sudo reboot
```

Na reboot werd Docker gecontroleerd met:

```bash
docker --version
docker compose version
```

---

## 7. Mapstructuur voor Zigbee2MQTT

Er werd een map aangemaakt voor Zigbee2MQTT:

```bash
mkdir -p ~/zigbee2mqtt/data
cd ~/zigbee2mqtt
```

De hoofdmap is:

```text
/home/<username>/zigbee2mqtt
```

De configuratiemap is:

```text
/home/<username>/zigbee2mqtt/data
```

---

## 8. SONOFF Zigbee dongle

De SONOFF Zigbee USB dongle werd in de Raspberry Pi gestoken.

De juiste seriële poort werd gecontroleerd met:

```bash
ls -l /dev/ttyUSB*
ls -l /dev/serial/by-id/
dmesg | tail -n 30
```

De dongle werd herkend als:

```text
/dev/ttyUSB0
```

In `dmesg` werd zichtbaar:

```text
Product: SONOFF Zigbee 3.0 USB Dongle Plus V2
Manufacturer: Itead
cp210x converter now attached to ttyUSB0
```

---

## 9. Docker Compose bestand

Het bestand werd aangemaakt met:

```bash
nano ~/zigbee2mqtt/docker-compose.yml
```

Inhoud:

```yaml
services:
  zigbee2mqtt:
    container_name: zigbee2mqtt
    image: koenkk/zigbee2mqtt
    restart: unless-stopped

    volumes:
      - ./data:/app/data

    ports:
      - 8080:8080

    environment:
      - TZ=Europe/Brussels

    devices:
      - /dev/ttyUSB0:/dev/ttyUSB0
```

Opslaan in nano:

```text
Ctrl + O
Enter
Ctrl + X
```

---

## 10. Zigbee2MQTT configuratie

Het configuratiebestand staat hier:

```text
/home/<username>/zigbee2mqtt/data/configuration.yaml
```

Openen:

```bash
nano ~/zigbee2mqtt/data/configuration.yaml
```

Huidige configuratie:

```yaml
homeassistant:
  enabled: true

mqtt:
  server: mqtt://<mqtt-broker-ip>:1883
  user: <mqtt-username>
  password: <mqtt-password>

serial:
  port: /dev/ttyUSB0
  adapter: ember

frontend:
  enabled: true
  port: 8080

version: 5
```

Na het koppelen van apparaten voegt Zigbee2MQTT automatisch een `devices:` sectie toe aan `configuration.yaml`.

Voorbeeld:

```yaml
devices:
  '0xd44867fffe4680a2':
    friendly_name: '0xd44867fffe4680a2'
```

Belangrijke instellingen:

| Instelling | Betekenis |
|---|---|
| `homeassistant.enabled: true` | apparaten automatisch doorsturen naar Home Assistant |
| `mqtt.server` | MQTT broker waar Zigbee2MQTT mee verbindt |
| `serial.port` | USB-poort van de Zigbee dongle |
| `adapter: ember` | adaptertype voor de SONOFF dongle |
| `frontend.port: 8080` | webinterface van Zigbee2MQTT |

---

## 11. MQTT broker

De MQTT broker draait niet op de Pi.

De MQTT broker draait op:

```text
<mqtt-broker-ip>
```

Home Assistant draait op:

```text
http://<home-assistant-ip>:8123
```

MQTT gegevens:

```text
Broker/server: <mqtt-broker-ip>
Poort: 1883
Username: <mqtt-username>
Password: <mqtt-password>
```

Netwerkconnectiviteit controleren:

```bash
ping -c 3 <mqtt-broker-ip>
nc -vz <mqtt-broker-ip> 1883
```

---

## 12. Zigbee2MQTT starten

Zigbee2MQTT starten:

```bash
cd ~/zigbee2mqtt
docker compose up -d
```

Status/logs bekijken:

```bash
cd ~/zigbee2mqtt
docker compose logs --tail=50
```

Live logs bekijken:

```bash
cd ~/zigbee2mqtt
docker compose logs -f
```

Herstarten:

```bash
cd ~/zigbee2mqtt
docker compose restart
```

Stoppen:

```bash
cd ~/zigbee2mqtt
docker compose down
```

Status van containers bekijken:

```bash
docker compose ps
```

---

## 13. Controleren of Zigbee2MQTT werkt

In de logs moet staan:

```text
Connected to MQTT server
Started frontend on port 8080
Zigbee2MQTT started!
```

Voorbeeld van werkende logs:

```text
Connected to MQTT server
Started frontend on port 8080
Currently 12 devices are joined.
Zigbee2MQTT started!
```

De webinterface is bereikbaar via:

```text
http://<ip-van-de-pi>:8080
```

Voorbeeld:

```text
http://192.168.1.100:8080 (dit is niet het echte ip-adres)
```

---

## 14. Problemen oplossen

### USB dongle niet gevonden

Controleer:

```bash
ls -l /dev/ttyUSB*
dmesg | tail -n 30
```

### Zigbee2MQTT kan MQTT niet bereiken

Controleer:

```bash
ping -c 3 <mqtt-broker-ip>
nc -vz <mqtt-broker-ip> 1883
```

### Logs bekijken

```bash
cd ~/zigbee2mqtt
docker compose logs -f
```

### Container status bekijken

```bash
docker compose ps
```

### Container volledig herstarten

```bash
cd ~/zigbee2mqtt
docker compose down
docker compose up -d
```

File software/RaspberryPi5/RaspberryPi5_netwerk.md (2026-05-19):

# Netwerkconfiguratie Raspberry Pi 5

Deze documentatie beschrijft hoe de Raspberry Pi 5 verbonden werd met het netwerk voor het gebruik van Zigbee2MQTT en Home Assistant.

---

## 1. Oorspronkelijke bedoeling

De oorspronkelijke bedoeling was om de Raspberry Pi rechtstreeks via ethernet te verbinden met het schoolnetwerk.

Schema:

```text
Schoolnetwerk
        ↓ ethernet
Raspberry Pi 5
```

Hiervoor moest het MAC-adres van de Raspberry Pi eerst goedgekeurd/geregistreerd worden door de school.

De Raspberry Pi gebruikte hiervoor het ethernet MAC-adres:

```text
<ethernet-mac>
```

Na goedkeuring zou de Raspberry Pi rechtstreeks netwerktoegang krijgen via het schoolnetwerk.

Voordelen van deze oplossing:

- stabiele ethernetverbinding
- geen extra netwerkapparatuur nodig
- rechtstreeks bereikbaar op schoolnetwerk
- eenvoudigere netwerkstructuur

---

## 2. Tijdelijke oplossing via hotspot

Omdat de netwerkregistratie nog niet volledig in orde was, werd tijdelijk een hotspot gebruikt.

Schema:

```text
Telefoon hotspot
        ↓
Raspberry Pi 5
```

Nadelen van deze oplossing:

- minder stabiele verbinding
- IP-adres kon regelmatig veranderen
- afhankelijk van mobiele data
- minder geschikt voor langdurig gebruik

---

## 3. Huidige oplossing via mini-router

Momenteel wordt een mini-router gebruikt als tussenoplossing.

Schema:

```text
Schoolwifi
        ↓
Mini-router
        ↓ ethernet
Raspberry Pi 5
```

De mini-router verbindt eerst met de schoolwifi.

Daarna maakt de mini-router een eigen lokaal netwerk aan.

De Raspberry Pi is via ethernet verbonden met deze mini-router.

Hierdoor krijgt de Raspberry Pi een lokaal IP-adres van de mini-router.

Voorbeeld:

```text
192.168.8.42
```

---

## 4. Huidige netwerkwerking

De Raspberry Pi gebruikt momenteel:

```text
eth0 (ethernet)
```

De Pi gebruikt dus niet rechtstreeks de schoolwifi.

De mini-router verzorgt:

- wifi verbinding met schoolnetwerk
- lokaal netwerk voor de Raspberry Pi
- DHCP/IP-adressen
- internettoegang

Ondanks deze tussenlaag kan de Raspberry Pi nog steeds communiceren met:

- MQTT broker
- Home Assistant
- internet

---

## 5. MQTT en Home Assistant connectiviteit

De Raspberry Pi maakt verbinding met de MQTT broker via:

```text
<mqtt-broker-ip>:1883
```

Home Assistant draait op:

```text
http://<home-assistant-ip>:8123
```

De connectiviteit kan gecontroleerd worden met:

```bash
ping -c 3 <mqtt-broker-ip>
```

Als deze ping werkt, kan Zigbee2MQTT normaal communiceren met Home Assistant via MQTT.

---

## 6. Belangrijke gevolgen van deze netwerkstructuur

### IP-adres van de Pi kan veranderen

Omdat de mini-router DHCP gebruikt, kan het IP-adres van de Raspberry Pi veranderen.

Bijvoorbeeld:

```text
192.168.8.42
```

kan later veranderen naar:

```text
192.168.8.55
```

Hierdoor veranderen:

- SSH verbinding
- Zigbee2MQTT webinterface URL

Voorbeelden:

```bash
ssh <username>@<nieuw-ip>
```

```text
http://<nieuw-ip>:8080
```

---

## 7. Wat verandert NIET bij een nieuw IP-adres

Deze onderdelen blijven normaal werken:

- Docker
- Zigbee2MQTT configuratie
- gekoppelde Zigbee apparaten
- MQTT instellingen
- Home Assistant MQTT discovery
- Home Assistant automations

Omdat Zigbee2MQTT zelf verbinding maakt naar de MQTT broker via:

```yaml
mqtt:
  server: mqtt://<mqtt-broker-ip>:1883
```

wordt het lokale IP-adres van de Raspberry Pi hier niet gebruikt.

---

## 8. Netwerkgegevens controleren

IP-adressen bekijken:

```bash
hostname -I
```

Ethernet interface bekijken:

```bash
ip a show eth0
```

Wifi verbinding controleren:

```bash
iwgetid
```

Netwerkinterfaces bekijken:

```bash
ip link
```

---

## 9. Zigbee2MQTT webinterface

De Zigbee2MQTT webinterface is bereikbaar via:

```text
http://<ip-van-de-pi>:8080
```

Voorbeeld:

```text
http://192.168.8.42:8080
```

---

## 10. SSH verbinding

SSH verbinding maken met de Raspberry Pi:

```bash
ssh <username>@<ip-van-de-pi>
```

Voorbeeld:

```bash
ssh lab@192.168.8.42 
```

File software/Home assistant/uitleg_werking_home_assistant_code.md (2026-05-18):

# Werking Home Assistant YAML: Van Knop tot Ledstrip en Website

In dit project werken verschillende YAML-bestanden samen om de status van ziekenhuisbedden (of vergelijkbare statussen) bij te houden, dit weer te geven op een dashboard (de website) en een fysieke ledstrip de juiste kleur te geven. 

Hieronder volgt een korte uitleg van de werking:

## 1. De Status: `input_select` (De Website/Backend)
Alles draait om zogenaamde `input_select` entiteiten (zoals `input_select.bed1_c314`). Dit zijn in wezen dropdown-menu's in Home Assistant. 
- Deze houden de huidige status van een bed bij: bijvoorbeeld `standby`, `call` (oproep), `extra` (nood), of `present` (aanwezig).
- **Op de website:** Je ziet deze statussen direct terug op het Home Assistant dashboard. Als de status in de achtergrond verandert, verandert dit ook op je scherm.

## 2. De Knoppen
De bestanden voor de knoppen bevatten automatisaties of acties die gekoppeld zijn aan fysieke zigbee knopen. 
- Zodra iemand op een knop drukt, voert de code in het YAML-bestand een actie uit.
- Die actie past de status van een `input_select` (bijv. van bed 1) aan naar `call` of `present`.

## 3. De Master Ledstrip
De ledstrip automatisatie functioneert als de regisseur voor de lampen. Het proces werkt in 4 stappen:

1. **Triggers:** Het bestand "luistert" constant naar **veranderingen** in alle gekoppelde `input_select` entiteiten. Zodra er via de UI/website óf via een fysieke knop iets verandert, start deze automatisatie.
2. **Variabelen (Tellen):** De code verzamelt alle bedden en telt hoeveel bedden er de status `extra`, `call` of `present` hebben.
3. **Logica (Choose/Conditions):** Home Assistant kijkt aan de hand van voorwaarden (prioriteiten) welke kleur de strip moet krijgen:
   - **Blauw:** Als er minstens 1 `extra` (nood) is, of als er **meer dan 1** `call` tegelijk is.
   - **Rood:** Als er precies **1** `call` is (en geen `extra`).
   - **Oranje:** Als er geen calls zijn, maar er wel iemand `present` is.
4. **Actie (Uitvoering):** Tot slot stuurt Home Assistant een commando naar de slimme ledstrip (`light.0xe4b3...`) met de juiste kleur en maximale helderheid (255), of schakelt hij deze uit (default) als er geen actieve statussen zijn.

## Samenvatting van de keten (Flow)
1. Verpleger/Patiënt drukt op fysieke knop 
2. `input_select` (status) verandert. 👉 *(Website toont de nieuwe status)* 🌐
3. `ledstrip...yml` registreert de verandering en telt de prioriteiten op.
4. De ledstrip (hardware) kleurt automatisch mee. 💡

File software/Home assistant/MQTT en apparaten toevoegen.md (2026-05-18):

# Apparaten toevoegen in Home Assistant via Zigbee2MQTT 

Deze handleiding beschrijft hoe je MQTT controleert in Home Assistant en hoe je via Zigbee2MQTT Zigbee-apparaten toevoegt.

## Stap 1 instellingen

Ga op het beginscherm van Home Assistant naar Instellingen (linksonder).
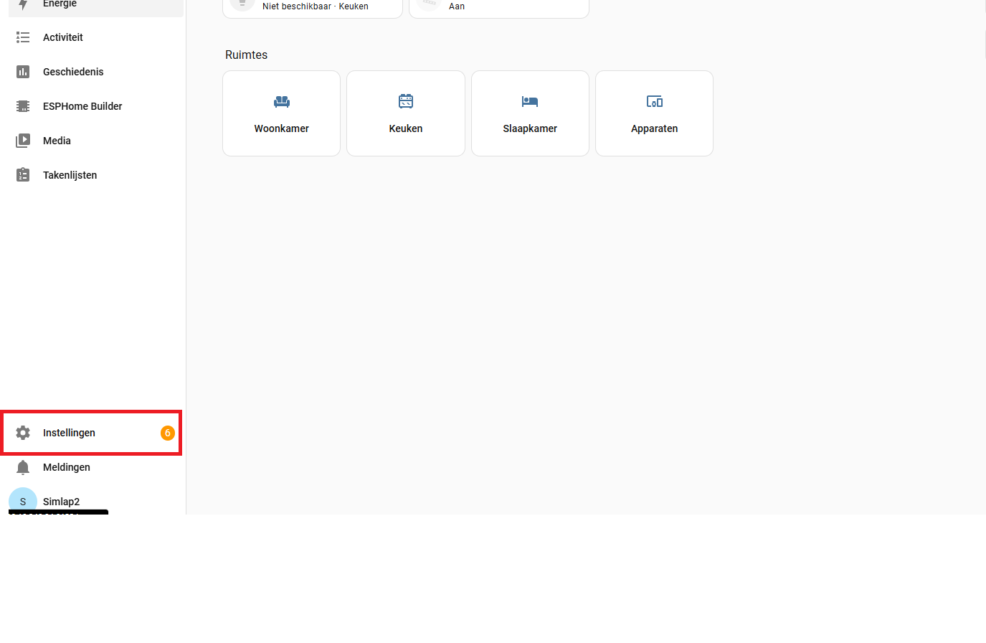
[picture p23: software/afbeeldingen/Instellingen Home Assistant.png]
Instelling Home Assistant


## Stap 2 apparaten en diensten

Klik op Apparaten en diensten.
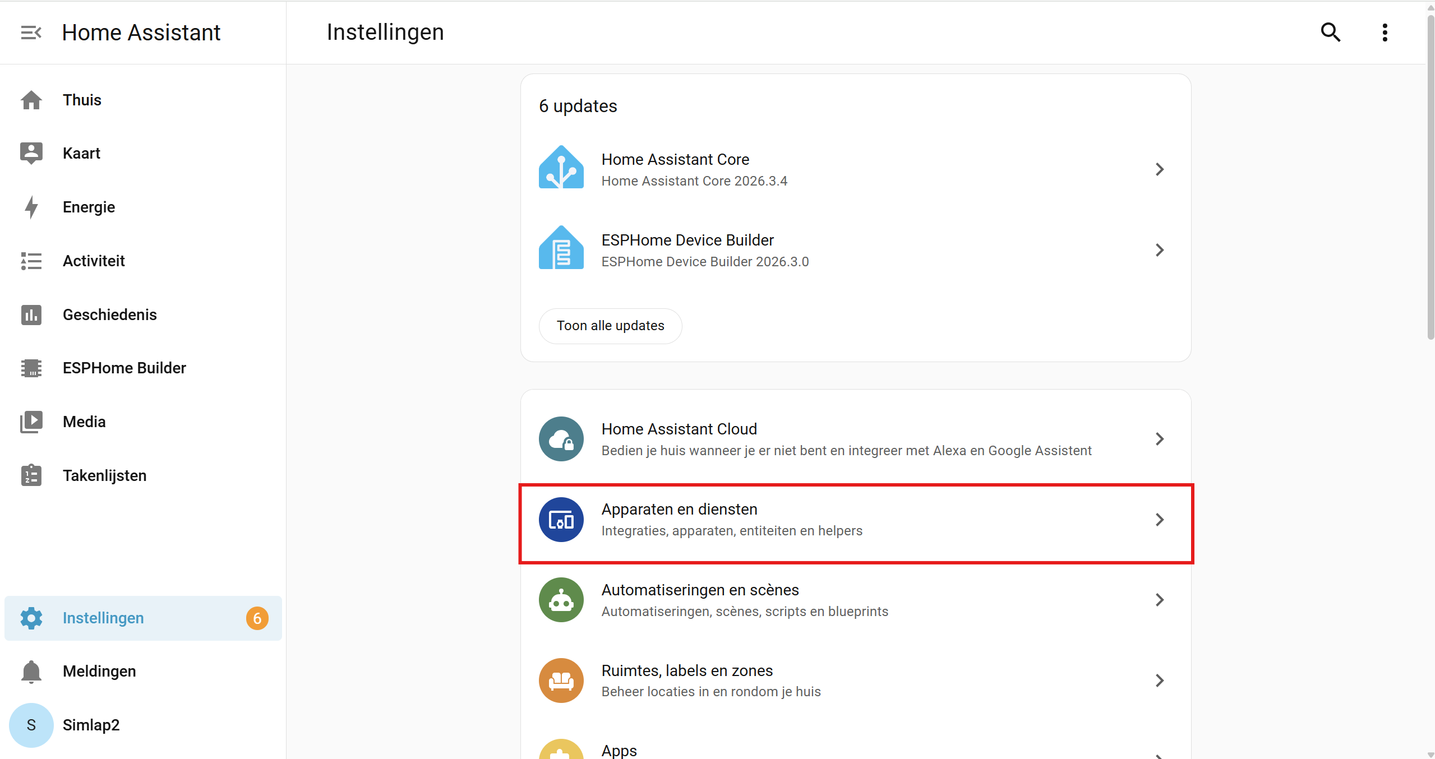
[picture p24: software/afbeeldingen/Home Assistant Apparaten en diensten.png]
Apparaten en Diensten Home Assistant


## Stap 3 kijken of MQTT al aanwezig is of toevoegen

1. Controleer of MQTT al in de lijst staat  
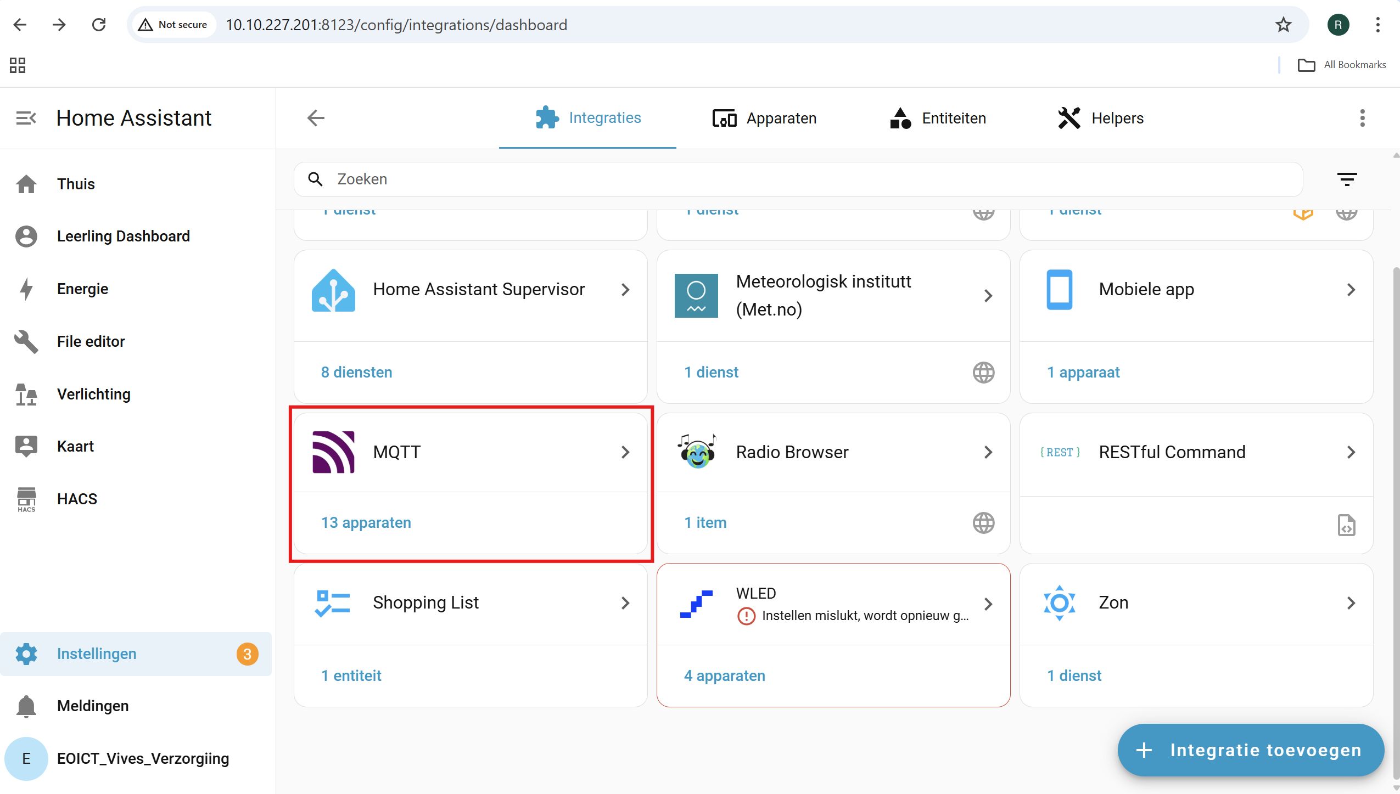
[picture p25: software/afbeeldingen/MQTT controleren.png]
Zigbee Home Automation bij Apparaten en Diensten
    

2. Staat deze er niet? Klik rechtsonder op Integratie toevoegen  
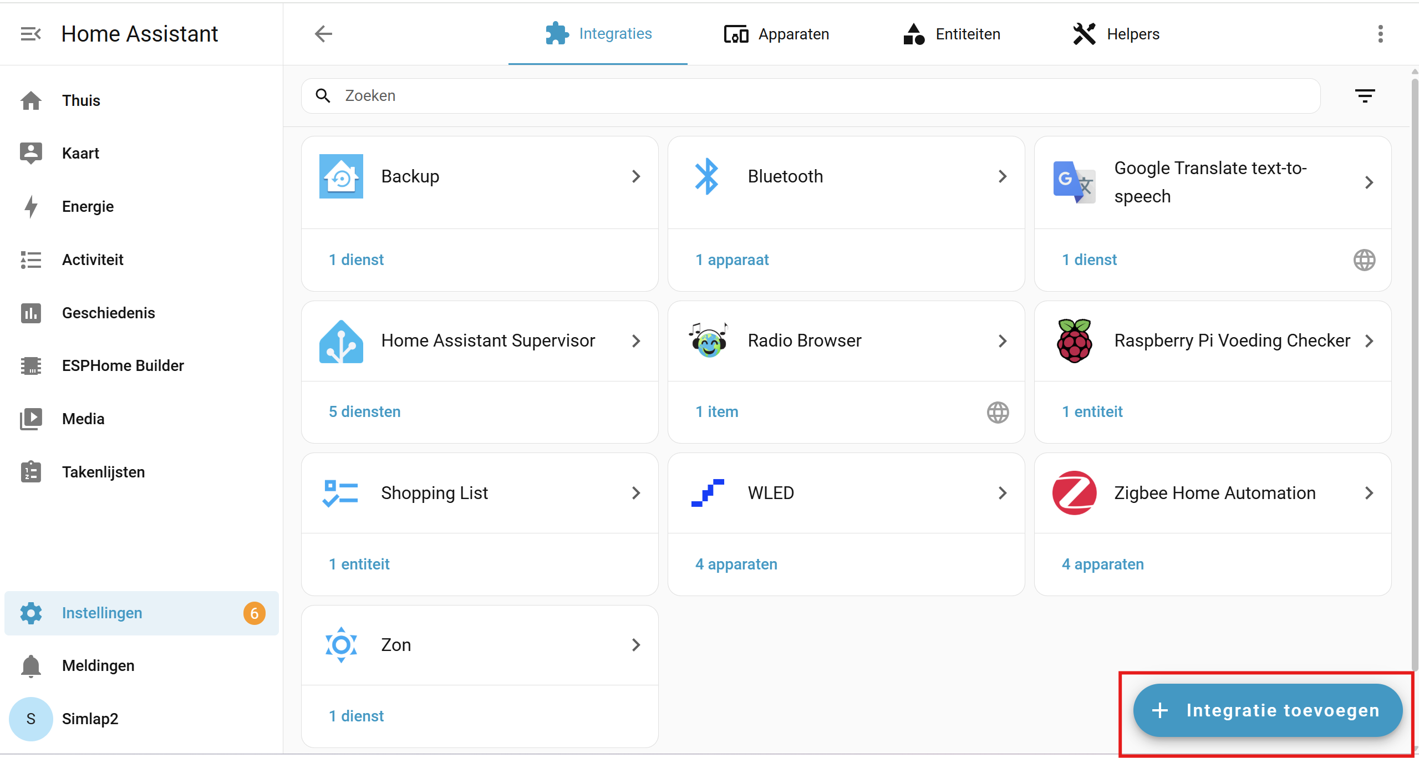
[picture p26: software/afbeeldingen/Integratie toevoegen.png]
Integratie toevoegen
    

3. Zoek naar MQTT en klik erop  
    <p align="center">MQTT integratie toevoegen</p>

4. Dan kom je op dit scherm en klik op het bovenste MQTT  
    <p align="center">Wat wil je toevoegen</p>

5. Dan krijg je een scherm waar je de broker/server, username en password kan invullen
   - Broker/server: `<broker-ip>`
   - Poort: `1883` (standaard MQTT poort)
   - Username: `<username>`
   - Password: `<password>`

6. Na de installatie zou MQTT in de lijst met integraties moeten staan

## Stap 4

Ga naar `http://<ip-van-de-pi>:8080` (de webinterface van Zigbee2MQTT)

Voorbeeld:
http://192.168.8.42:8080

(Belangrijk: je moet op dezelfde wifi zitten als je Pi)

Dan zou je op dit scherm moeten komen.
<p align="center">Zigbee2MQTT pagina</p>

## Stap 5 Permit Join aanzetten in Zigbee2MQTT

Klik linksonder op de knop Permit Join 
<p align="center">Permit Join in Zigbee2MQTT</p>

Controleer of "Permit Join" nog actief is.
Deze knop schakelt automatisch terug uit na een bepaalde tijd.

## Stap 6 Zet je apparaten in koppelmodus

### ESP32 in koppelmodus zetten

Zorg er eerst voor dat de juiste code erop staat.
In de code moet ingesteld zijn dat de ESP32 automatisch probeert te verbinden na een reset.

Als deze functie in de code aanwezig is, druk dan op de resetknop van de ESP32.
De ESP32 zal daarna automatisch proberen te verbinden met Zigbee2MQTT.

### SONOFF Zigbee Wireless Switch in koppelmodus zetten

Aan de zijkant van de knop zit een klein rond knopje.
Hou dit knopje ongeveer 5 seconden ingedrukt.

## Stap 7 apparaten controleren

Wacht tot het apparaat verschijnt in de Zigbee2MQTT pagina.

Als alles correct werkt, zou het apparaat hier moeten verschijnen.
<p align="center">ESP32 toegevoegd in Zigbee2MQTT</p>

## Stap 8 apparaatnaam wijzigen in Zigbee2MQTT

Je kan ervoor kiezen om de naam van het apparaat te veranderen in Zigbee2MQTT.

Klik hiervoor op Devices links op je scherm.
<p align="center">Devices in Zigbee2MQTT</p>

Dan kom je op deze pagina.
Klik daar op het blauwe icoontje.
<p align="center">Naam wijzigen in Zigbee2MQTT</p>

Dan kom je op dit scherm.
<p align="center">Naam wijzigen scherm in Zigbee2MQTT</p>

Hier kan je de naam veranderen naar wat je wilt.
Hier kan je ook op het vakje klikken (Update Home Assistant entity ID).

Dan probeert Zigbee2MQTT ook de Home Assistant entity IDs mee te veranderen.

### Opgelet:

Als je al apparaten hebt gebruikt in Home Assistant code en je gaat nu de naam aanpassen in Zigbee2MQTT, kan dit ervoor zorgen dat de bestaande Home Assistant automations niet meer werken.

Daarom wordt aangeraden om namen enkel in Home Assistant aan te passen of eerst de naam aan te passen in Zigbee2MQTT voordat je het apparaat gebruikt in Home Assistant.

## Stap 9 apparaat controleren in Home Assistant

Controleer of je apparaat zichtbaar is in Home Assistant.

Ga naar Instellingen.
Klik op Apparaten en diensten.
Klik op MQTT.
Kijk of hier je apparaat staat.
<p align="center">Controle van apparaten in MQTT</p>

Als je apparaat daar staat, is het in orde.

## Stap 10 naam aanpassen in Home Assistant + apparaat aan een kamer toevoegen

Klik rechts op het potloodicoon.
<p align="center">Potloodicoon in Home Assistant</p>

Dan kom je op dit scherm.
<p align="center">Naam wijzigen in Home Assistant</p>

Hier kan je de naam van het apparaat aanpassen voor in Home Assistant.
Je kan het apparaat hier ook aan een kamer toevoegen.

## Problemen oplossen

### 1. Apparaat wordt niet gevonden

1. Controleer of je apparaat in koppelmodus staat  
   (raadpleeg de handleiding van je apparaat om te zien hoe dit moet)

2. Zet het apparaat dichter bij je Zigbee stick

3. Probeer het apparaat eerst te resetten

### 2. Nog steeds problemen met toevoegen?

1. Herstart Home Assistant  
   → Zet Home Assistant even uit en weer aan

2. Trek je Zigbee stick uit en steek hem opnieuw in  
   → Haal de stick uit de Raspberry Pi en steek hem opnieuw in

3. Zoek hulp online  
   → Raadpleeg de handleiding van je apparaat of zoek op forums

4. Controleer of MQTT verbonden is  
   → Controleer in Home Assistant of de MQTT integratie actief is.

5. Controleer of Zigbee2MQTT bereikbaar is

   Open:  
   `http://<ip-van-de-pi>:8080`

   Controleer of de Zigbee2MQTT webinterface correct opent.

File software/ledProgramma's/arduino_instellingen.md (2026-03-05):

# Arduino IDE instellen voor de ESP32-C6 als Zigbee-apparaat

Om je ESP32-C6 DevKit te gebruiken in een Zigbee-netwerk, moet je de Arduino IDE specifiek configureren. Volg hiervoor deze stappen:

## 1. De juiste library installeren
Zorg dat je de Espressif ESP32-boardmodule hebt geïnstalleerd.
1. Ga naar **File → Preferences**.
2. Voeg deze URL toe bij *Additional Board Manager URLs*: 
   `https://espressif.github.io/arduino-esp32/package_esp32_dev_index.json`
3. Ga naar **Tools → Board → Boards Manager**, zoek op `esp32` en installeer de versie van Espressif Systems.

## 2. Het juiste board selecteren
Sluit de ESP32-C6 aan op je computer. Ga naar **Tools → Board → esp32** en selecteer:
* **ESP32C6 Dev Module**
Je kunt dan links bovenaan zien in je arduino ide dat je het juiste board hebt:

[esp32_C6_devkit_tonen](./afbeeldingen/esp32%20c6%20devkit%20tonen.png)

## 3. Cruciale Zigbee-instellingen (Tools menu)
Pas vervolgens de volgende drie instellingen aan onder het **Tools** menu. Zonder deze instellingen zal je ESP32 nooit als 
Zigbee-apparaat werken.

### A. Erase All Flash Before Sketch Upload: `Enabled`
- **Wat het doet:** Wist het volledige flashgeheugen voordat de nieuwe code wordt geüpload.
- **Waarom:** Dit verwijdert eventuele oude code of achtergebleven Zigbee-netwerkgegevens. Als je dit niet doet, kan Home Assistant 
vaak moeite hebben om het apparaat te herkennen of te pairen. (Tip: zet dit na de eerste succesvolle upload weer uit, anders moet je 
hem telkens opnieuw pairen).

### B. Partition Scheme: `Zigbee 4MB with spiffs`
- **Wat het doet:** Deelt het geheugen van de ESP32 op een specifieke manier in.
- **Waarom:** De Zigbee-software heeft een gereserveerde partitie (`zb_storage`) nodig om netwerkgegevens en koppelingssleutels in 
op te slaan. Met een standaard partitieschema ontbreekt deze opslagruimte en zal de ESP blijven crashen tijdens het opstarten.

### C. Zigbee Mode: `Zigbee ED (end device)`
- **Wat het doet:** Bepaalt de rol van de ESP32 binnen het Zigbee-netwerk.
- **Waarom:** Een Zigbee-netwerk heeft maar één leider (de coördinator, in dit geval Home Assistant). Jouw ESP32 fungeert als een 
uitvoerend eindapparaat (End Device) dat opdrachten ontvangt, zoals het schakelen van een ledstrip.

[arduino insellingen](./afbeeldingen/instellingen%20arduino%20ide.png)

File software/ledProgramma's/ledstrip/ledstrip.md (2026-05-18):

# Uitleg ledstrip.ino

Dit bestand bevat de eerste versie van de code voor de ESP32-C6 die de ledstrip aanstuurt, maar zonder het automatisch uitvallen.

De ESP32-C6 werkt als Zigbee-apparaat en wordt gekoppeld met Zigbee2MQTT. Via Zigbee ontvangt de ESP32 signalen van Home Assistant. Op basis van deze signalen wordt de ledstrip aangestuurd.

## Wat doet deze code?

De code zorgt ervoor dat:

- de ESP32-C6 verbinding maakt via Zigbee
- de ledstrip kan worden aangestuurd
- verschillende statussen zichtbaar worden via kleuren of effecten
- de ledstrip reageert op commando’s vanuit Home Assistant/Zigbee2MQTT

## Waarvoor wordt deze code gebruikt?

Deze code werd gebruikt voor de ledstrip aan het bed.  
De ledstrip geeft visueel de status van het meldingssysteem weer.

## Belangrijk

Dit bestand bevat een oudere versie van de code.

De huidige versie die gebruikt wordt in het project is:
`ledstrip_met_uitvallen.ino`

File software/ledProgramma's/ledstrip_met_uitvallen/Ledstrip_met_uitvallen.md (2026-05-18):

# Ledstrip met automatisch uitschakelen

Deze code is gebaseerd op `ledstrip.ino`.

## Wat is er toegevoegd?

- Na het opstarten en succesvol verbinden met Zigbee blijft de ledstrip 3 seconden groen als indicatie dat alles correct werkt.
- De code houdt bij wanneer de laatste activiteit gebeurt.
- Activiteit betekent:
  - een Zigbee-commando vanuit Home Assistant
  - of een druk op de knop
- Bij elke activiteit wordt de timer opnieuw gestart.
- Als er gedurende 1 uur geen activiteit is, gaat de ESP32 automatisch in deep sleep.
- Voor de ESP32 in deep sleep gaat, wordt de ledstrip volledig uitgeschakeld.
- Omdat de ESP32 daarna bijna geen stroom meer verbruikt, schakelt de powerbank zichzelf automatisch uit na ongeveer 30 seconden.

Om de ledstrip opnieuw te gebruiken, moet de powerbank opnieuw ingeschakeld worden.

---

## Timer voor geen activiteit

```cpp
unsigned long lastActivityTime = 0;
const unsigned long sleepTimeout = 3600000; // 1h
```

`lastActivityTime` houdt bij wanneer de laatste activiteit was.

`sleepTimeout` bepaalt hoelang de ESP32 mag aanblijven zonder activiteit.

Voorbeelden:

```cpp
const unsigned long sleepTimeout = 60000;   // 1 minuut
const unsigned long sleepTimeout = 300000;  // 5 minuten
const unsigned long sleepTimeout = 3600000; // 1 uur
```

Alles staat in milliseconden.

---

## Timer resetten bij Zigbee-activiteit

```cpp
lastActivityTime = millis();
```

Deze regel staat in `setLightAndColor()`.

Daardoor wordt de timer opnieuw gestart wanneer Home Assistant een commando naar de ledstrip stuurt.

---

## Groene indicatie na Zigbee-verbinding

```cpp
strip.setBrightness(100);

for (int i = 0; i < strip.numPixels(); i++) {
  strip.setPixelColor(i, strip.Color(0, 255, 0));
}

strip.show();

delay(3000);

strip.clear();
strip.show();
```

Als de ESP32 verbonden is met Zigbee, brandt de ledstrip 3 seconden groen.

Daarna wordt de ledstrip terug uitgezet.

---

## Timer resetten bij knopdruk

```cpp
lastActivityTime = millis();
```

Deze regel staat ook bij de knopcontrole.

Daardoor telt een knopdruk ook als activiteit.

---

## Deep sleep na 1 uur zonder activiteit

```cpp
if (millis() - lastActivityTime > sleepTimeout) {

  Serial.println("No activity for 1 h. Going to deep sleep.");

  strip.clear();
  strip.show();

  delay(100);

  esp_deep_sleep_start();
}
```

Deze code controleert of er langer dan `sleepTimeout` geen activiteit is geweest.

Als dat zo is:
- de ledstrip wordt uitgezet
- de ESP32 gaat in deep sleep
- de powerbank schakelt daarna vanzelf uit

---

## Opnieuw gebruiken

Om de ledstrip opnieuw te gebruiken, moet de powerbank opnieuw ingeschakeld worden.

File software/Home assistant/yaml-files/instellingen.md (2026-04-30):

# YAML-bestanden Gebruiken

De meegeleverde YAML-bestanden bevatten de automatiseringen die je in Home Assistant moet aanmaken. In principe kun je deze in de interface visueel aanmaken, maar rechtstreeks de YAML-code bewerken is een stuk sneller. In deze map vind je twee submappen, namelijk voor kamer C302 en C305. Dit zijn de voorgemaakte YAML-bestanden voor de knoppen en Master Ledstrip in de betreffende kamer. Om deze bestanden voor jouw opstelling correct te laten werken, moet je enkele parameters aanpassen. Hieronder lees je precies hoe je dit doet.

## Knoppen

### ID aanpassen 

Iedere Zigbee-knop heeft een uniek apparaat-ID (Device ID). Om ervoor te zorgen dat de automatisering reageert op de juiste fysieke knop, moet je deze ID in het YAML-bestand op drie specifieke plaatsen invullen.

Id aanpassen

Je kunt dit apparaat-ID vinden in Home Assistant zodra je de knop succesvol hebt toegevoegd. Navigeer naar de apparaatpagina van deze specifieke knop en bekijk de URL in de zoekbalk van je browser; het lange nummer is je ID.

Id vinden

### Namen aanpassen 
De entiteitsnamen (`entity_id`) in de code moeten overeenkomen met de specifieke "Helper" (`input_select`) die je per bed hebt aangemaakt. Dit proces wordt stap voor stap uitgelegd in de handleiding [Helper aanmaken](/software/Homa%20assistant/Helpers%20en%20Automatisering%20.md). 
Controleer de naam van je helpers en vul deze in onder `entity_id`. Let er ook op dat je het REST-API commando bij `action` aanpast naar het logische formaat voor jouw project, oftewel: lokaal en bednummer (bijv. `rest_command.send_call_c302_1`).

Namen knop

## Master Ledstrip

Per kamer is er bovendien één `ledstrip.yml` bestand dat als "Master" dient. Deze logica plak je ook in een nieuwe automatisering en stuur je aan door de juiste namen en ID's te koppelen.

### ID aanpassen 
Iedere ledstrip-controller krijgt vanuit Zigbee2MQTT of Home Assistant een unieke Entiteit-ID toegewezen. Vul deze ID op vier plaatsen in de YAML-code in `target -> entity_id` in, zodat de juiste lamp gaat branden.

Id aanpassen ledstrip

Je vindt de exacte entiteitsnaam van de ledstrip als volgt: 
Navigeer naar **Instellingen** → **Apparaten & Diensten** → **MQTT** en klik op je ledstrip-apparaat in de bestemde kamer. Klik vervolgens op het lamp/schakelaar-icoontje bij bediening, open het instellingen-tandwieltje rechtsboven in de pop-up en kopieer vanaf daar de "Entiteit-ID" (meestal beginnend met `light.`).

Id zoeken

Id vinden ledstrip

### Bedden toevoegen
De ledstrip-code is ontworpen om makkelijk op te schalen. Als je een nieuw bedbed aan de kamer toevoegt, voeg je gewoon eenvoudig de naam van de nieuwe helper toe aan de lijst onder de `triggers` en `variables`. De prioriteit (`extra`, `call`, `present`) van alle opgesomde bedden wordt dan automatisch foutloos berekend!

Bedden toevoegen

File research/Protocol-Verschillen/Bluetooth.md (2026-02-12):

## Voordelen bluetooth (BLE / BLE Mesh)
- Werkt zonder WiFi-infrastructuur (geen access points nodig om te functioneren).
- Laag energieverbruik is haalbaar met BLE, dus geschikt voor batterijgevoede 
drukknoppen/sensor-nodes.
- ESP32 heeft native BLE-ondersteuning (dus je hoeft geen extra radio-module te
 plaatsen als je bij ESP32 blijft).
- Uitbreidbaar naar veel apparaten als je BLE Mesh gebruikt (BLE Mesh is ontworpen om 
grote aantallen nodes te ondersteunen).
- Beveiliging: BLE Mesh gebruikt encryptie en authenticatie (AES-CCM) om berichten te 
beschermen.
- Wordt al gebruikt in healthcare-contexten (bv. asset tracking/RTLS), dus er is 
relevante praktijkervaring en ecosysteem.

## Nadelen bluetooth
- Kortere indoor range is typisch (vaak rond 10–50 m; afhankelijk van muren/omgeving), 
dus je hebt sneller meerdere “tussen-nodes” nodig.
- “Klassieke” BLE is vooral point-to-point; voor meerdere kamers/beds heb je BLE Mesh 
nodig, en dat is aanzienlijk complexer om goed op te zetten en te testen.
- Op ESP32 kan BLE tijdens actieve verbinding relatief veel stroom trekken (orde 50–70 
mA), waardoor je ontwerp sterk moet leunen op sleep/advertising om echt low-power te
 blijven.
- Op ESP32 delen WiFi en Bluetooth dezelfde radio/antenne-resources, wat gelijktijdig 
gebruik kan beperken (relevant als je toch ergens WiFi wil combineren).
- In ziekenhuizen zie je Bluetooth vaker als infrastructuur voor tracking/management 
dan als primair “kritisch” oproepsysteem, dus je moet extra aandacht geven aan 
betrouwbaarheid en fail-safe ontwerp.

## Meer info over bluetooth mesh 
https://novelbits.io/bluetooth-mesh-networking-the-ultimate-guide/

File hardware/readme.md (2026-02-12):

# Hardware
In dit document zal alles te maken met de hardware van dit project terug te vinden zijn.

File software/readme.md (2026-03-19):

# Software
In deze map zal alles te maken met de software terug te vinden zijn.

- [Home Assistant backup en herstel bij SD-card crash](./README_backup_sd_crash.md)

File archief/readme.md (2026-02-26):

# Archief
In deze map zullen bestanden voor documentatie (afbeeldingen, referenties, handleidingen, ...) en project ideeën die niet zullen gebruikt worden terug te vinden zijn.

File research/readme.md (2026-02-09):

# Onderzoek
In dit document worden de verschillende onderzoeken toegelicht die zijn uitgevoerd om tot een degelijk en betrouwbaar eindresultaat te komen. Daarnaast worden de gemaakte keuzes onderbouwd en wordt per beslissing uitgelegd waarom juist deze hardware- en softwareoplossingen zijn geselecteerd. Zo ontstaat een helder overzicht van het onderzoeksproces en de argumentatie achter de uiteindelijke aanpak.

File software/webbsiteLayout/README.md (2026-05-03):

# WebsiteLayout

Deze map is alleen bedoeld voor de website en PWA van het SimLab verpleegoproepsysteem.

Gebruik de PWA-map voor de webapp:

```text
webbsiteLayout/
`-- PWA/
    |-- README.md
    |-- backend/
    `-- frontend/
```

De uitleg in deze map gaat enkel over:

- frontend;
- backend;
- API;
- login;
- push notifications;
- PWA-bestanden;
- website troubleshooting;
- deployment van de website.

Uitleg over hardware, Home Assistant, Zigbee, MQTT en ledstrips hoort in de andere documentatiemappen of repositories.

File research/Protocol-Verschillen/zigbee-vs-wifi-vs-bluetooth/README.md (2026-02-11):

# Soorten communicatie vergelijken

## Wi-Fi

**Voordelig:**

- **Schaalbaarheid:** Het is makkelijk om meerdere toestellen toe te voegen aan een netwerk. Voor ons is dit voordelig omdat ons project communicatie nodig heeft tussen meerdere onderdelen.

- **Mobiel:** Overal bereikbaar zolang het binnen de zone van het netwerk blijft.

- **Bandbreedte:** Ook al is dit een voordeel, is dit niet noodzakelijk. Wij zullen niet heel zware data moeten doorsturen.

**Nadelig:**

- **Bereikbeperkingen:** Wi-Fi heeft een beperkt bereik die kan worden beïnvloed door fysieke obstakels (muren, meubels) en door interferentie van andere apparaten. Dit kan ervoor zorgen dat er in bepaalde gebieden een zwak signaal is, zeker als het signaal al niet sterk was.

- **Stroomverbruik:** Het gebruik van Wi-Fi verbruikt redelijk veel stroom vergeleken met de andere opties. Dit is voor ons project nadelig omdat we met een low-power systeem willen werken en de batterij lang moet kunnen meegaan. Het is niet de bedoeling dat de batterij bijna dagelijks moet herladen worden, daarom weegt dit nadeel sterk door.

## Bluetooth

**Voordelig:**

- **Laag stroomverbruik**: Bluetooth is een goed keuze voor communicatie met een laag stroomverbruik, waardoor het geschikt is voor apparaten die op batterijen werken. Dit is perfect voor ons project.

- **Toegankelijkheid**: Bluetooth is een breed geaccepteerde standaard, waardoor het compatibel is met een groot aantal apparaten. Het kan met veel verschillende soorten toestellen verbinden en daardoor ook voor veel verschillende toepassingen gebruikt worden.

**Nadelig:**

- **Bereikbeperkingen:** Bluetooth heeft een kort bereik, waardoor het niet op heel lange afstanden kan gebruikt worden. Dit kan voor ons project eventueel voor problemen zorgen.

- **Schaalbaarheid**: Bluetooth heeft een limiet op het aantal apparaten dat tegelijkertijd verbonden kan worden, wat een beperking kan zijn in complexe opstellingen. Dit nadeel weegt veel door omdat ons project makkelijk uitbreid baar moet zijn en bestaat uit een netwerk van knoppen en lichten.

## Zigbee

**Voordelig:**

- **Laag stroomverbruik**: Zigbee apparaten gebruiken een systeem waarbij ze in een soort slaapstand staan, hierdoor wordt er heel weinig energie verbruikt. Dit is ideaal voor ons project. Hierdoor moet de batterij minder vaak herladen worden en zal het toestel lang kunnen gebruikt worden.

- **Mesh netwerk:** Zigbee maakt gebruik van een mesh netwerk, waarbij apparaten signalen versterken en doorgeven. Dit zorgt voor een stabiele verbinding en een groot bereik.

- **Schaalbaarheid**: Zigbee kan tot 65.000 apparaten in één netwerk ondersteunen, wat het zeer geschikt maakt voor grote installaties. Deze eigenschap is zeer nuttig bruikbaar voor ons project, dit systeem is perfect voor complexere netwerken en op deze manier voorzien we ook een mogelijkheid voor uitbreiding.

**Nadelig:**

- **Lagere bandbreedte**: De bandbreedte van Zigbee is relatief laag, waardoor het minder geschikt is voor toepassingen die veel data vereisen. Dit is niet een zeer groot nadeel omdat we geen zeer grote data zullen moeten doorsturen.

- **Lagere datasnelheid**: In vergelijking met de andere keuzes heeft Zigbee een lage snelheid voor dataoverdracht. Dit betekend niet dat het onbruikbaar is, Zigbee werkt uitstekend voor sensoren en automatisering. Voor onze toepassing is dit snel genoeg.

## Conclusie

We zullen gebruik maken van Zigbee, dit komt omdat we met ons project de nadruk leggen op de levensduur van de batterij en de uitbreid mogelijkheden. Zigbee verbruikt zeer weinig energie, waardoor de batterij lang meegaat. Ook is Zigbee goed voor het maken van complexere netwerken, wat nuttig is voor dit project. Dit betekend niet dat deze manier perfect is, Zigbee heeft geen heel hoge bandbreedte en is ook niet zeer snel. Dit zijn echter kleine compensaties vergeleken met de voordelen.

**Bronnen:**

[IoT Wireless Tech: Wi-Fi, Bluetooth, Zigbee – Guide & Comparison - Stats and Insights](https://statsandinsights.com/2025/01/13/iot-wireless-tech-wifi-bluetooth-zigbee-guide-comparison/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)

[Wat zijn de voor- en nadelen van wifi?](https://www.nldit.com/netwerken/wireless-networking/202510/327674.html)

[17 Voordelen en nadelen van Bluetooth](https://barrazacarlos.com/nl/voordelen-en-nadelen-van-bluetooth/)

[Wat zijn de voor- en nadelen van Zigbee](https://homey.app/nl-be/wiki/wat-is-zigbee/)

[Zigbee vs. Z-Wave: Dit zijn de Verschillen!](https://domotiseren.nl/particulier/zigbee-vs-zwave/)

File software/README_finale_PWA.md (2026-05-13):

# SimLab Verpleegoproep - Finale PWA (Proof of Concept)

## 1. Projectbeschrijving
Dit project is een demo van een verpleegoproepsysteem voor een simulatieomgeving verpleegkunde.

Het systeem koppelt Home Assistant aan een aparte website op een andere VM. Wanneer een knop in Home Assistant wordt ingedrukt, wordt de status van een kamer doorgestuurd naar een webdashboard. Dat dashboard toont live de status van de kamer.

Dit project is gebouwd als **proof of concept** voor een simulatiekamer, met focus op:

- knopdrukken detecteren
- verschillende statussen tonen
- live updates op de website
- dashboard op gsm tonen
- demo-klaar opleveren

## 2. Doel van het systeem
Het doel is om op een eenvoudige, visuele manier te tonen welke kamer hulp nodig heeft en in welke status die oproep zit.

Concreet:

- snelle opvolging van oproepen in een simulatiecontext
- duidelijke kleurfeedback per kamer
- centrale logica in Home Assistant
- lichte en toegankelijke webweergave op mobiel en desktop

## 3. Architectuur en communicatie tussen de onderdelen
### Overzicht van de 2 hoofdonderdelen
1. **Home Assistant VM** (op Proxmox)
2. **Website VM** (Debian + Node.js + nginx)

### Eenvoudige tekstuele architectuurweergave
```text
[Knop / Event]
      |
      v
[Home Assistant VM]
  - Automations
  - Scenes
  - Notificaties
  - rest_command
      |
      | HTTP POST /api/call
      v
[Website VM - Node.js/Express API]
  - bewaart actuele kamerstatus
      |
      | GET /api/state (polling)
      v
[Frontend Dashboard]
  - kamerkaarten
  - tellers
  - kleuren en iconen
  - toastmeldingen
```

### Waarom deze opzet
Door de netwerkopstelling kon de website VM niet rechtstreeks naar Home Assistant communiceren, maar Home Assistant kon wel naar de website VM sturen.

Daarom is gekozen voor:

- Home Assistant als centrale logica
- website als visuele laag
- unidirectionele flow van Home Assistant naar website

## 4. Overzicht van de gebruikte technologieen
- Home Assistant
- Home Assistant automations
- Home Assistant `rest_command`
- Node.js
- Express
- HTML
- CSS
- JavaScript
- nginx
- Proxmox
- Debian Linux

## 5. Setup van de website server
### Node.js installeren
```bash
apt update
apt install -y nodejs npm
```

### Projectmap aanmaken
```bash
cd /root/simlab-api/backend
npm install
```

De dependencies staan in `backend/package.json`. De huidige backend gebruikt onder andere:

```json
{
  "scripts": {
    "start": "node server.js"
  },
  "dependencies": {
    "body-parser": "^1.20.2",
    "cors": "^2.8.5",
    "dotenv": "^16.4.5",
    "express": "^4.18.2",
    "express-session": "^1.17.3",
    "web-push": "^3.6.6"
  }
}
```

### Server starten
Voor tijdelijk testen:
```bash
npm start
```

Voor op de achtergrond:
```bash
pm2 start server.js --name simlab-api
pm2 save
```

### nginx reverse proxy
Gebruik nginx om domeinverkeer door te sturen naar Node.js op poort `3000`.

Voorbeeldconfiguratie:
```nginx
server {
    listen 80;
    server_name verpleegkunde.voltlab.net;

    location / {
        proxy_pass http://127.0.0.1:3000;
        proxy_http_version 1.1;
        proxy_set_header Host $host;
        proxy_set_header X-Real-IP $remote_addr;
        proxy_set_header X-Forwarded-For $proxy_add_x_forwarded_for;
        proxy_set_header X-Forwarded-Proto $scheme;
    }
}
```

## 6. Setup van Home Assistant
Home Assistant draait op een aparte VM in Proxmox en bevat:

- automations
- knoplogica
- scenes
- notificaties
- `rest_command` configuratie

Voorbeeld in `configuration.yaml`:

```yaml
rest_command:
  send_call_c302_1:
    url: "http://<BACKEND-IP>:3000/api/call"
    method: post
    content_type: "application/json"
    payload: >
      {
        "room": "C302",
        "bed": "1",
        "bedId": "C302_1",
        "status": "call"
      }

  send_present_c302_1:
    url: "http://<BACKEND-IP>:3000/api/call"
    method: post
    content_type: "application/json"
    payload: >
      {
        "room": "C302",
        "bed": "1",
        "bedId": "C302_1",
        "status": "present"
      }

  send_idle_c302_1:
    url: "http://<BACKEND-IP>:3000/api/call"
    method: post
    content_type: "application/json"
    payload: >
      {
        "room": "C302",
        "bed": "1",
        "bedId": "C302_1",
        "status": "idle"
      }
```

## 7. Uitleg van de API
De Node.js server draait op poort `3000`.

### `POST /api/call`
Wordt gebruikt door Home Assistant om een status door te sturen.

Voorbeeld payload:

```json
{
  "room": "C302",
  "bed": "1",
  "bedId": "C302_1",
  "status": "call"
}
```

De echte backend verwerkt deze payload zo:

```js
app.post("/api/call", (req, res) => {
    const { room, bed, bedId, status } = req.body;
    const normalizedStatus = status || "idle";
    const normalizedBedId = normalizeBedId(room, bed, bedId);

    beds[normalizedBedId] = normalizedStatus;

    console.log("Update ontvangen:", {
        room,
        bed,
        bedId: normalizedBedId,
        status: normalizedStatus
    });

    sendNotifications({
        room,
        bed,
        bedId: normalizedBedId,
        status: normalizedStatus
    });

    res.json({ success: true });
});
```

Ondersteunde statussen:

- `idle` = geen melding
- `call` = hulp gevraagd
- `present` = collega aanwezig
- `extra` = extra hulp nodig / collega hulp gevraagd
- `low_battery` = lage batterij

### `GET /api/state`
Geeft de huidige toestand van alle kamers terug in JSON-formaat.

Deze endpoint wordt door de frontend periodiek opgevraagd om live te updaten.

De huidige backend houdt deze bedden bij:

```js
const beds = {
    C302_1: "idle",
    C302_2: "idle",
    C302_3: "idle",
    C302_4: "idle",
    C314_1: "idle",
    C314_2: "idle",
    C314_3: "idle",
    C314_4: "idle",
    C314_5: "idle",
    C314_6: "idle"
};
```

De response wordt opgebouwd met tellers:

```js
app.get("/api/state", requireLogin, (req, res) => {
    res.json({
        beds,
        counts: calculateCounts()
    });
});
```

## 8. Uitleg van de frontend
De frontend bestaat uit:

- `index.html`
- `resources/css/stylesheet.css`
- `resources/js/script.js`

Functionaliteit:

- toont kamerkaarten
- toont overzicht met tellers
- toont legende met kleuren
- controleert de login via `/api/me`
- haalt ongeveer elke 1,2 seconden status op via `/api/state`
- past kleuren en iconen dynamisch aan
- toont toastmelding bij statusverandering

De echte polling-code uit `resources/js/script.js`:

```js
async function fetchState() {
    try {
        const res = await fetch("/api/state", { cache: "no-store" });

        if (res.status === 401) {
            window.location.href = "/login.html";
            return;
        }

        const data = await res.json();
        const beds = data.beds || {};
        const counts = data.counts || { help: 0, colleague: 0, lowBat: 0 };

        for (const bedId of Object.keys(beds)) {
            updateBed(bedId, beds[bedId]);
        }

        updateCounters(counts);
        maybeNotify(beds);
    } catch (err) {
        console.error(err);
    }
}
```

De frontend start daarna met:

```js
async function init() {
    const user = await fetchCurrentUser();
    if (!user) return;

    await fetchState();
    setInterval(fetchState, 1200);
}
```

Kleurlegende:

- groen = geen hulp
- rood = hulp gevraagd
- oranje = collega aanwezig
- blauw = collega hulp gevraagd / extra hulp nodig

## 9. Uitleg van de Home Assistant automatisaties
Er zijn drie hoofdacties via de knop:

- korte klik -> hulp nodig
- dubbele klik -> hulp aanwezig
- lang indrukken -> extra hulp nodig

Daarnaast is er reset naar groen (`idle`).

De automatisaties sturen:

- scenes
- notificaties
- het juiste `rest_command` naar de website API

Belangrijk:

- de website-status klopt alleen als de juiste payload verstuurd wordt
- als steeds dezelfde payload verstuurd wordt, blijven kleuren fout of onveranderd

## 10. Stap-voor-stap workflow van knopdruk tot website update
1. Er wordt op een knop gedrukt.
2. Home Assistant vangt het event op.
3. Een automation wordt uitgevoerd.
4. Eventueel worden scene en notificatie geactiveerd.
5. Home Assistant stuurt via `rest_command` een HTTP POST naar `POST /api/call`.
6. De Node.js server verwerkt en bewaart de nieuwe status.
7. De frontend vraagt via `GET /api/state` de actuele status op.
8. De kamerkaart op de website verandert van kleur/tekst en eventueel verschijnt een toast.

## 11. Troubleshooting
### Website laadt niet
Controleer of Node.js draait:

```bash
pm2 status
```

### Oude website blijft zichtbaar
Leeg browsercache met harde refresh:

```text
Ctrl + Shift + R
```

### API niet bereikbaar
Test lokaal op de website VM:

```bash
curl -X POST http://127.0.0.1:3000/api/call \
  -H "Content-Type: application/json" \
  -d '{"room":"C302","bed":"1","bedId":"C302_1","status":"call"}'
```

Let op: `GET /api/state` vraagt een ingelogde browsersessie. Voor een snelle API-test is `POST /api/call` daarom makkelijker.

### Home Assistant stuurt niets door
Controleer:

- `configuration.yaml`
- `rest_command` definities
- automation triggers en acties
- payloadinhoud (`room`, `bed`, `bedId` en `status`)

### Website verandert niet van kleur
Controleer of de status exact overeenkomt met de frontend-logica:

- `idle`
- `call`
- `present`
- `extra`

## 12. Bekende beperkingen
- momenteel gericht op kamers C302 en C314
- frontend gebruikt polling (geen websockets)
- login/rollenmodel is aanwezig, maar wachtwoorden staan eenvoudig in `users.json`
- pushnotificaties zijn aanwezig, maar vragen correcte VAPID keys en HTTPS buiten localhost
- reset naar `idle` moet expliciet doorgestuurd worden

## 13. Mogelijke uitbreidingen
- meerdere kamers tegelijk live koppelen
- wachtwoorden veilig hashen in plaats van plain text bewaren
- API-key toevoegen voor `POST /api/call`
- websockets in plaats van polling
- live batterijtelemetrie
- logging en historiek
- rechten per gebruiker

## 14. Folderstructuur
### Deploy-structuur op de website VM
```text
/root/simlab-api
|-- backend
|   |-- server.js
|   |-- package.json
|   |-- users.json
|   `-- push-subscriptions.json
`-- frontend
    |-- index.html
    |-- login.html
    |-- settings.html
    |-- manifest.webmanifest
    |-- sw.js
    |-- icon.svg
    `-- resources
        |-- css
        |   `-- stylesheet.css
        `-- js
            |-- script.js
            |-- push.js
            |-- login.js
            `-- settings.js
```

### Relevante structuur in deze repository
```text
software/
|-- readme.md
|-- README_finale_PWA.md
|-- Home assistant/
|-- ledProgramma's/
`-- webbsiteLayout/
    `-- PWA/
        |-- backend/
        |   |-- server.js
        |   |-- package.json
        |   |-- users.example.json
        |   `-- push-subscriptions.example.json
        `-- frontend/
            |-- index.html
            |-- login.html
            |-- settings.html
            `-- resources/
                |-- css/stylesheet.css
                `-- js/
                    |-- script.js
                    `-- push.js
```

## 15. Demo-uitleg
Tijdens de demo verloopt de flow als volgt:

1. Een gebruiker drukt op de knop.
2. Home Assistant verwerkt het event in een automation.
3. Home Assistant activeert (indien nodig) scene en notificatie.
4. Home Assistant stuurt de nieuwe status naar de website API.
5. Het dashboard toont vrijwel meteen de nieuwe toestand.

Demo-statussen:

- groen = geen hulp
- rood = hulp gevraagd
- oranje = collega aanwezig
- blauw = collega hulp gevraagd / extra hulp nodig

---

## Korte samenvatting
Dit project toont een werkende keten van **fysieke knopactie** naar **live webvisualisatie** via Home Assistant en een Node.js API. De gekozen architectuur is eenvoudig, robuust genoeg voor demo-doeleinden en vormt een goede basis voor latere uitbreiding naar een volledige productieoplossing met PWA, rollen en realtime communicatie.

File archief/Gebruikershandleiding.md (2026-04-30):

# Gebruikershandleiding

## Inleiding
Dit bestand bevat een uitgebreide handleiding bestemd voor de gebruiker van het systeem, er zullen geen technische details of diepgang voorkomen.

## Installatie

## Gebruik knop
Bij iedere melding of verandering van in de app, krijgt iedere medewerker (docent en student) die op dat moment zijn ingelogd een bijhorende melding.

### Meldingen patiënt
#### Hulp gevraagd
Wanneer de patiënt hulp nodig heeft drukt deze **1x kort**op de knop.

Dit zorgt ervoor dat het bijhorende bed op de app rood kleurt, deze als “Hulp gevraagd” geregistreerd wordt en indien er geen belangrijkere meldingen zijn zal de lamp van de kamer rood kleuren.

### Personeel (medewerker)
#### Aanwezigheid registreren
Als de medewerker aanwezigheid wilt registreren wanneer er voordien hulp gevraagd werd, kan dit door **2x kort na elkaar** op de knop te drukken waar de melding vandaan kwam.

Dit zorgt ervoor dat het bijhorende bed op de app van rood naar oranje kleuren, deze als “Collega aanwezig” geregistreerd wordt en indien er geen belangrijkere meldingen zijn zal de lamp van de kamer oranje kleuren.

#### Uitschakelen
Als de medewerker de melding wilt afhandelen of uitschakelen kan dit door **1x kort** op de bijhorende knop te drukken (enkel als deze al brand anders wordt er om hulp gevraagd).

Hierdoor zal het bijhorende bed op de app terug groen kleuren en de lamp van de bijhorende kamer uitgeschakeld worden indien er geen andere meldingen zijn.

#### Extra hulp nodig
Als de medewerker **1x lang** de knop indrukt (ongeveer 2s-3s), zal er een extra hulp aanvraag verzonden worden.
Ook als er meer dan 1 "Hulp gevraagd" meldingen in een kamer zijn zal automatisch extra hulp opgeropen worden.

Dit zorgt ervoor dat het bijhorende bed op de app blauw brand, deze als “Extra hulp nodig” geregistreerd wordt en de lamp van de bijhorende kamer blauw kleurt.

**Instructieblad:**

## Onderhoud
### Lamp
Zorg ervoor dat de poerbank in de behuizing regelmatig gecontroleerd wordt.

### Knop

## FAQ

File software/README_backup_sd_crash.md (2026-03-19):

# Home Assistant Backup en Herstel (SD-card crash)

Deze handleiding is bedoeld voor het scenario: SD-kaart crasht en je wil zo snel mogelijk terug online.

Bronnen:
- https://www.home-assistant.io/integrations/backup/
- https://www.home-assistant.io/common-tasks/general/#backups
- https://www.home-assistant.io/common-tasks/general/#restoring-a-backup
- https://www.home-assistant.io/common-tasks/general/#defining-backup-locations
- https://www.home-assistant.io/more-info/backup-emergency-kit/

## Waarom dit belangrijk is

Backups zijn de snelste manier om:
- na crash te herstellen
- naar nieuwe hardware te migreren
- configuratieverlies te vermijden

Als backups alleen lokaal op de SD-kaart staan en die kaart faalt, ben je ze kwijt. Bewaar daarom altijd minstens 1 kopie buiten Home Assistant.

## Aanbevolen backup-strategie

1. Zet automatische backups aan (liefst dagelijks).
2. Gebruik meerdere locaties:
- lokaal (snelle restore)
- extern (NAS/cloud/off-site)
3. Bewaar de Backup Emergency Kit op een veilige plek buiten HA.
4. Hou meerdere recente backups bij (bijv. 7 of 14).

## Automatische backups instellen

1. Ga naar `Settings > System > Backups`.
2. Kies `Set up backups`.
3. Download de `Backup emergency kit` en bewaar die veilig.
4. Stel schema in:
- frequentie: bij voorkeur dagelijks
- tijdstip: wanneer netwerkopslag beschikbaar is
5. Stel in of je ook voor updates automatisch wil backuppen.
6. Kies retentie (hoeveel backups je bewaart).
7. Kies wat je opneemt in de backup.
- tip: `media` en `share` uitschakelen als backup te groot is
8. Zet backup-locaties aan (lokaal + extern).

## Backup-locaties

Aanbevolen minimum:
- 1 lokale backup
- 1 externe backup (NAS / cloud / Home Assistant Cloud)

Belangrijk:
- Home Assistant Cloud bewaart 1 backup (max 5 GB) en die is altijd encrypted.
- Voor andere locaties kan je encryptie per locatie instellen.

## Handmatige backup (voor grote wijzigingen)

Maak handmatig een backup voor je grote updates doet:

1. `Settings > System > Backups`
2. `Backup now` > `Manual backup`
3. Naam geven
4. Locaties kiezen
5. Backup starten

## Noodherstel na SD-card crash (nieuw toestel of nieuwe SD)

1. Installeer Home Assistant opnieuw op het nieuwe medium/toestel.
2. Start onboarding.
3. Kies hersteloptie:
- `Upload backup` (lokale .tar)
- of `Home Assistant Cloud` (inloggen en backup kiezen)
4. Kies onderdelen om te herstellen (meestal alles).
5. Geef encryptiesleutel in uit de Backup Emergency Kit.
6. Wacht tot restore volledig klaar is (kan lang duren).
- pagina niet forceren verversen tijdens restore
7. Log in met dezelfde credentials als op moment van backup.
8. Controleer nadien:
- integraties online
- netwerkopslag opnieuw gekoppeld
- Zigbee/Z-Wave sticks correct aangesloten

## Wat in de emergency kit moet staan

Bewaar buiten HA (bijvoorbeeld password manager + versleutelde USB):
- encryptiesleutel
- backup naam + datum
- HA URL
- beheerderslogin (of verwijzing ernaar)
- notitie welke sleutel bij welke oudere backups hoort

Opmerking:
Als je ooit de encryptiesleutel wijzigt, hou ook de oude sleutel bij voor oudere backups.

## Snelle maandelijkse checklist

1. Is er een recente succesvolle backup?
2. Staat er een kopie buiten Home Assistant?
3. Is de emergency kit up-to-date en terugvindbaar?
4. Is backupgrootte nog onder controle?
5. Is minstens 1 restore-test ooit uitgevoerd?

## Optioneel: backup via automation action

Als de standaard planning niet volstaat, kan je de backup actions gebruiken:
- `backup.create_automatic`
- `backup.create` (core/container)

Voorbeeld:

```yaml
automation:
  - alias: "Backup Home Assistant every night at 3 AM"
    triggers:
      - trigger: time
        at: "03:00:00"
    actions:
      - alias: "Create backup now"
        action: backup.create
```

## Besluit

Voor SD-card crash bescherming heb je 3 dingen nodig:
- automatische backups
- externe opslag
- emergency kit

Als die 3 op orde staan, kan je meestal snel volledig herstellen.

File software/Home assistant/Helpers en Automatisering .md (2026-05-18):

# Helpers Toevoegen

We maken gebruik van Helpers om goed te communiceren met de website voor het meldingssysteem.

---

## Helpers maken

Om een helper aan te maken ga je naar:

**Instellingen → Apparaten en diensten**

<br>

<p align="center">
  Instellingen Home Assistant
</p>

<br>

<p align="center">
  Apparaten en diensten
</p>

<br>

Dan selecteer je bovenaan het tabblad **Helpers**.

<br>

<p align="center">
  Helpers tabblad
</p>

<br>

Klik daarna onderaan op **Helper aanmaken**.

Ga vervolgens in de lijst zoeken naar **Keuzelijst**.  
Kies een naam, bij voorkeur in het formaat:

`Bed..._C...`

Zo kun je later in je automatiseringen makkelijk namen aanpassen zonder alles te moeten kopiëren.

Daarna voeg je bij opties de volgende 4 waarden toe:

- idle
- present
- call
- extra

<br>

<p align="center">
  Helper aanmaken
</p>

---

# Automatisering Toevoegen  
*(Dit is een testvoorbeeld maar gebruiken we niet)*

Dit moet worden gedaan omdat de knop en de ESP met ledstrip twee aparte apparaten zijn en dus niet rechtstreeks met elkaar kunnen verbinden. Daarom wordt er gebruikgemaakt van een automatisering die bepaalt: als dit gebeurt, moet dat worden uitgevoerd.

---

## Automatisering maken

In Home Assistant ga je naar:

**Instellingen → Automatiseringen en scènes**

en klik je vervolgens bovenaan op **Scènes**.

<br>

<p align="center">
  Instellingen Home Assistant
</p>

<br>

<p align="center">
  Automatiseringen en scènes
</p>

<br>

Je komt standaard op het automatiseringsblad terecht, dus druk je rechtsonder op **Automatisering toevoegen**.

<br>

<p align="center">
  Automatisering toevoegen
</p>

<br>

Op het tweede scherm klik je opnieuw op **Automatisering toevoegen**.  
Daarna krijg je dit scherm te zien.

<br>

<p align="center">
  Automatisering maken
</p>

---

Het eerste wat je doet is een trigger aanmaken voor de knop.

Klik hiervoor op **Trigger toevoegen** en kies **Apparaat**.  
Daarna verschijnt dit scherm.

<br>

<p align="center">
  Trigger apparaat
</p>

<br>

Daarna ga je in de lijst zoeken naar het apparaat dat je wilt gebruiken voor de trigger.  
In ons geval is dit de **eWeLink SNZB-01P**.

Selecteer dit apparaat. Vervolgens moet je de trigger kiezen.  
In dit geval kiezen we voor:

**Drukknop → knop ingedrukt**

Dan moet je dit zien staan.

<br>

<p align="center">
  Trigger correct
</p>

---

De volgende stap is het toevoegen van een actie.

Klik op **Actie toevoegen** en kies **Scène toevoegen**.  
Selecteer daarna **Inschakelen**.

Vervolgens klik je op **Doel toevoegen** en kies je de gewenste scène.  
In ons geval is dat **demo**.

<br>

<p align="center">
  Actie maken
</p>

<br>

Daarna hoef je enkel nog de automatisering op te slaan en een naam naar keuze te geven.  
Vervolgens is de automatisering klaar voor gebruik.

---

# Automatisering uitzetten  
*(Dit moet je maar doen bij 1 van de drie automatiseringen)*

Nu heb je wel het probleem dat je de scène kunt aanzetten, maar nog niet kunt uitzetten. Hiervoor moet je een kleine aanpassing doen in je demo.

Als je meerdere scènes gebruikt die je met één drukknop inschakelt, hoef je maar één keer een uit-functie te maken om alle scènes die je hebt uit te schakelen.

---

## Als-dan functie toevoegen

Bij **Actie toevoegen** ga je bovenaan naar **Bouwstenen** en kies je **Als-dan voorwaarde**.

Bij **Als** voeg je het apparaat `unk_manufacturer unk_model` toe en stel je in dat het uitgeschakeld is.

Daarna voeg je bij **Dan** de instelling **Scène toevoegen** toe en selecteer je de gewenste scène.

Vervolgens voeg je bij **Anders** de actie toe om `unk_manufacturer unk_model` uit te zetten.

<br>

<p align="center">
  Als-dan functie
</p>

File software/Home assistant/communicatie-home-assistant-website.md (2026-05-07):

# Communicatie tussen Home Assistant en de Website

## SimLab Verpleegoproepsysteem

Dit document beschrijft de productiearchitectuur waarmee Home Assistant, Zigbee-knoppen en de SimLab website met elkaar communiceren.

De huidige versie gebruikt REST-communicatie. Home Assistant stuurt statusupdates via HTTP POST requests naar de Node.js backend. De frontend haalt de actuele toestand daarna op via polling.

> Belangrijk: de website communiceert niet rechtstreeks met Home Assistant. Alle statusupdates lopen via REST naar de backend.

## Doel van de Communicatie

Het SimLab verpleegoproepsysteem wordt gebruikt in simulatiekamers van de opleiding verpleegkunde. Studenten kunnen met een fysieke Zigbee-knop een oproepstatus doorgeven. Leerkrachten en studenten zien de status live op een lokaal dashboard.

Belangrijke doelen:

| Doel | Uitleg |
| --- | --- |
| Volledig lokaal | De communicatie blijft binnen het schoolnetwerk. |
| Geen cloudafhankelijkheid | Home Assistant, backend en frontend draaien lokaal. |
| Eenvoudige uitbreiding | Nieuwe kamers en bedden kunnen met extra REST commands worden toegevoegd. |
| Stabiel dashboard | De frontend haalt status op via een eenvoudige REST endpoint. |
| Gebruiksvriendelijk | Statussen worden als duidelijke kleuren, labels, tellers en meldingen getoond. |

## Architectuur Overzicht

```text
Zigbee knop
    |
    v
Home Assistant
    |
    v
Automation trigger
    |
    v
REST command
    |
    v
HTTP POST /api/call
    |
    v
Node.js / Express backend
    |
    v
Interne bedstatus wordt bijgewerkt
    |
    v
Frontend pollt GET /api/state
    |
    v
Dashboard toont actuele kamerstatus
```

## Netwerkarchitectuur

```text
Schoolnetwerk / lokaal SimLab netwerk

+-------------------+        Zigbee        +----------------------+
| Zigbee knoppen    | -------------------> | Home Assistant       |
| per bed           |                      | Raspberry Pi / VM    |
+-------------------+                      +----------+-----------+
                                                      |
                                                      | HTTP POST
                                                      | REST command
                                                      v
                                           +----------+-----------+
                                           | Debian VM            |
                                           | Node.js / Express    |
                                           | PM2                  |
                                           +----------+-----------+
                                                      |
                                                      | reverse proxy
                                                      v
                                           +----------+-----------+
                                           | Nginx                |
                                           | Website / PWA        |
                                           +----------+-----------+
                                                      ^
                                                      |
                                             Browser pollt /api/state
```

## Hoofdcomponenten

| Component | Rol |
| --- | --- |
| Zigbee knop | Fysieke invoer per bed. |
| Home Assistant | Ontvangt knopacties en voert automations uit. |
| REST command | Stuurt vanuit Home Assistant een HTTP POST naar de backend. |
| Node.js backend | Ontvangt statusupdates, bewaart de actuele state en levert API endpoints. |
| Frontend | Toont kamers, bedden, tellers, toastmeldingen en push notification controls. |
| Nginx | Reverse proxy naar de Node.js app. |
| PM2 | Houdt de Node.js backend actief op de Debian VM. |

## Statusmodel

Elke bedkaart heeft een unieke `bedId` in dit formaat:

```text
<kamer>_<bednummer>
```

Voorbeelden:

```text
C302_1
C302_2
C314_1
C314_6
```

De backend bewaart de actuele status in geheugen:

```js
const beds = {
  C302_1: "idle",
  C302_2: "idle",
  C302_3: "idle",
  C302_4: "idle",
  C314_1: "idle",
  C314_2: "idle",
  C314_3: "idle",
  C314_4: "idle",
  C314_5: "idle",
  C314_6: "idle"
};
```

## Ondersteunde Statussen

| Status | Betekenis | UI-kleur | Dashboardtekst |
| --- | --- | --- | --- |
| `idle` | Geen actieve melding | Groen | Geen melding |
| `call` | Hulp gevraagd | Rood | Hulp gevraagd |
| `present` | Collega aanwezig | Oranje | Collega aanwezig |
| `extra` | Extra hulp nodig | Blauw | Extra hulp nodig |
| `low_battery` | Lage batterij | Teller | Lage batterij |

`low_battery` wordt in de backend meegeteld in `counts.lowBat`. De huidige frontend toont vooral `idle`, `call`, `present` en `extra` als bedstatus.

## Statusflows

De knopacties worden in Home Assistant vertaald naar REST updates.

### Single Click

```text
idle -> call
```

Betekenis: student vraagt hulp.

Voorbeeldrequest naar de backend:

```http
POST /api/call
Content-Type: application/json

{
  "room": "C302",
  "bed": "1",
  "bedId": "C302_1",
  "status": "call"
}
```

### Double Click

```text
call -> present
```

Betekenis: een collega of leerkracht is aanwezig bij het bed.

Voorbeeldrequest:

```http
POST /api/call
Content-Type: application/json

{
  "room": "C302",
  "bed": "1",
  "bedId": "C302_1",
  "status": "present"
}
```

### Long Click

```text
present -> idle
```

Betekenis: de oproep is afgehandeld en het bed keert terug naar normale status.

Voorbeeldrequest:

```http
POST /api/call
Content-Type: application/json

{
  "room": "C302",
  "bed": "1",
  "bedId": "C302_1",
  "status": "idle"
}
```

> In sommige configuraties kan long click ook gebruikt worden voor `extra`. Kies per kamer een vaste afspraak en documenteer die in de automation.

## Home Assistant REST Commands

Home Assistant gebruikt `rest_command` om HTTP requests naar de Node.js backend te sturen. Elk command bevat:

- de URL van de backend;
- HTTP methode `POST`;
- JSON headers;
- een JSON body met kamer, bed en status.

Voorbeeld in `configuration.yaml`:

```yaml
rest_command:
  send_call_c302_1:
    url: "http://<BACKEND-IP>:3000/api/call"
    method: post
    content_type: "application/json"
    payload: >
      {
        "room": "C302",
        "bed": "1",
        "bedId": "C302_1",
        "status": "call"
      }

  send_present_c302_1:
    url: "http://<BACKEND-IP>:3000/api/call"
    method: post
    content_type: "application/json"
    payload: >
      {
        "room": "C302",
        "bed": "1",
        "bedId": "C302_1",
        "status": "present"
      }

  send_idle_c302_1:
    url: "http://<BACKEND-IP>:3000/api/call"
    method: post
    content_type: "application/json"
    payload: >
      {
        "room": "C302",
        "bed": "1",
        "bedId": "C302_1",
        "status": "idle"
      }
```

Vervang `<BACKEND-IP>` door het IP-adres of de DNS-naam van de Debian VM waarop de Node.js backend draait.

## Home Assistant Automation

Een automation koppelt een knopactie aan een REST command.

Voorbeeld:

```yaml
alias: Knop C302 Bed 1
description: "Verstuurt bedstatus naar SimLab backend"
triggers:
  - domain: mqtt
    device_id: 1788389a3b7df7b0d78b85bb4de7f5d9
    type: action
    subtype: single
    trigger: device
    id: single

  - domain: mqtt
    device_id: 1788389a3b7df7b0d78b85bb4de7f5d9
    type: action
    subtype: double
    trigger: device
    id: double

  - domain: mqtt
    device_id: 1788389a3b7df7b0d78b85bb4de7f5d9
    type: action
    subtype: long
    trigger: device
    id: long

actions:
  - choose:
      - conditions:
          - condition: trigger
            id: single
        sequence:
          - action: rest_command.send_call_c302_1

      - conditions:
          - condition: trigger
            id: double
        sequence:
          - action: rest_command.send_present_c302_1

      - conditions:
          - condition: trigger
            id: long
        sequence:
          - action: rest_command.send_idle_c302_1

mode: single
```

## Waarom Polling in de Frontend?

De frontend gebruikt polling naar:

```text
GET /api/state
```

De huidige polling interval is ongeveer:

```js
setInterval(fetchState, 1200);
```

Polling werd gekozen omdat deze aanpak in een schoolomgeving eenvoudiger en stabieler is:

| Reden | Uitleg |
| --- | --- |
| Minder afhankelijkheden | De browser hoeft geen Home Assistant sessie of token te beheren. |
| Simpel netwerkverkeer | Alleen gewone HTTP requests naar de eigen backend. |
| Betere fouttolerantie | Als een request faalt, probeert de volgende pollingronde opnieuw. |
| Eenvoudige debugging | API calls zijn zichtbaar in browser DevTools, PM2 logs en Nginx logs. |
| Geschikt voor lokaal gebruik | De updatefrequentie van 1,2 seconden voelt realtime aan voor een dashboard. |

## Backend Update Flow

Wanneer Home Assistant een REST command uitvoert:

```text
POST /api/call
    |
    v
Backend leest room, bed, bedId en status
    |
    v
Backend normaliseert bedId
    |
    v
beds[bedId] = status
    |
    v
Backend berekent tellers bij GET /api/state
    |
    v
Frontend ziet wijziging bij volgende pollingronde
```

## API Endpoints

### `GET /api/state`

Geeft de actuele bedstatussen en tellers terug.

Gebruikt door:

- frontend dashboard;
- niet rechtstreeks door Home Assistant.

Authenticatie:

- vereist een geldige sessie;
- zonder sessie antwoordt de backend met `401`.

Response:

```json
{
  "beds": {
    "C302_1": "idle",
    "C302_2": "call",
    "C302_3": "present",
    "C302_4": "extra",
    "C314_1": "idle"
  },
  "counts": {
    "help": 2,
    "colleague": 1,
    "lowBat": 0
  }
}
```

### `POST /api/call`

Ontvangt een statusupdate voor een bed.

Gebruikt door:

- Home Assistant REST commands;
- eventueel testtools zoals `curl` of Postman.

Authenticatie:

- deze endpoint is bedoeld voor Home Assistant en vereist in de huidige code geen browsersessie.

Request body:

```json
{
  "room": "C302",
  "bed": "1",
  "bedId": "C302_1",
  "status": "call"
}
```

Velden:

| Veld | Verplicht | Uitleg |
| --- | --- | --- |
| `room` | Aanbevolen | Kamernaam, bijvoorbeeld `C302`. |
| `bed` | Aanbevolen | Bednummer als string of nummer. |
| `bedId` | Optioneel | Volledige ID, bijvoorbeeld `C302_1`. |
| `status` | Optioneel | Nieuwe status. Zonder status wordt `idle` gebruikt. |

Response:

```json
{
  "success": true
}
```

Test:

```bash
curl -X POST http://localhost:3000/api/call \
  -H "Content-Type: application/json" \
  -d '{"room":"C302","bed":"1","bedId":"C302_1","status":"call"}'
```

### `GET /api/me`

Geeft de ingelogde gebruiker terug.

Gebruikt door:

- dashboard bij het openen;
- instellingenpagina voor rolcontrole.

Response:

```json
{
  "success": true,
  "user": {
    "username": "Leerkracht",
    "role": "leerkracht"
  }
}
```

### `POST /api/login`

Maakt een sessie aan met `express-session`.

Request:

```json
{
  "username": "Leerkracht",
  "password": "Leerkracht1"
}
```

Response:

```json
{
  "success": true,
  "user": {
    "username": "Leerkracht",
    "role": "leerkracht"
  }
}
```

Fout:

```json
{
  "success": false,
  "error": "Login mislukt"
}
```

### `POST /api/logout`

Vernietigt de sessie.

Response:

```json
{
  "success": true
}
```

### `GET /api/push/public-key`

Geeft de VAPID public key terug voor browser push notifications.

Gebruikt door:

- frontend wanneer de gebruiker meldingen inschakelt.

Response:

```json
{
  "publicKey": "B..."
}
```

### `POST /api/push/subscribe`

Slaat een browser push subscription op.

Gebruikt door:

- frontend na toestemming voor meldingen.

Request:

```json
{
  "endpoint": "https://...",
  "keys": {
    "p256dh": "...",
    "auth": "..."
  }
}
```

Response:

```json
{
  "success": true
}
```

### `POST /api/push/unsubscribe`

Verwijdert een browser push subscription.

Request:

```json
{
  "endpoint": "https://..."
}
```

Response:

```json
{
  "success": true
}
```

### `POST /api/change-password`

Wijzigt het wachtwoord van de ingelogde leerkracht.

Gebruikt door:

- instellingenpagina.

Authenticatie:

- vereist login;
- vereist rol `leerkracht`.

Request:

```json
{
  "currentPassword": "oud-wachtwoord",
  "newPassword": "nieuw-wachtwoord",
  "confirmPassword": "nieuw-wachtwoord"
}
```

Response:

```json
{
  "success": true,
  "message": "Eigen wachtwoord gewijzigd"
}
```

### `POST /api/change-student-password`

Wijzigt het wachtwoord van de leerling-account.

Gebruikt door:

- instellingenpagina voor leerkrachten.

Request:

```json
{
  "newPassword": "nieuw-wachtwoord",
  "confirmPassword": "nieuw-wachtwoord"
}
```

Response:

```json
{
  "success": true,
  "message": "Wachtwoord leerling gewijzigd"
}
```

## Push Notifications

Wanneer de backend een statusupdate ontvangt via `/api/call`, kan hij een push notification versturen naar opgeslagen browser subscriptions.

Voorwaarde:

- `VAPID_PUBLIC_KEY` is ingesteld;
- `VAPID_PRIVATE_KEY` is ingesteld;
- gebruiker heeft meldingen toegestaan in de browser;
- frontend heeft de subscription opgeslagen via `/api/push/subscribe`.

Push payload:

```json
{
  "title": "Nieuwe oproep",
  "body": "Kamer C302 bed 1: call",
  "icon": "/icon.svg",
  "badge": "/icon.svg",
  "data": {
    "url": "/"
  }
}
```

## Schaalbaarheid naar Meerdere Kamers

Een nieuwe kamer toevoegen bestaat uit vier stappen:

1. Voeg bedden toe aan de backend state.
2. Voeg bedkaarten toe aan de frontend.
3. Maak per bed REST commands aan in Home Assistant.
4. Maak per knop een automation die de juiste REST commands uitvoert.

Voorbeeld voor kamer `C401` bed `2`:

```json
{
  "room": "C401",
  "bed": "2",
  "bedId": "C401_2",
  "status": "call"
}
```

## Waarom deze Architectuur Stabieler is

De vorige aanpak liet de website rechtstreeks reageren op Home Assistant statuswijzigingen. De huidige aanpak scheidt verantwoordelijkheden duidelijker:

| Oud probleem | Nieuwe oplossing |
| --- | --- |
| Browser moest Home Assistant sessie/token kennen. | Alleen de backend communiceert indirect met Home Assistant via REST requests. |
| Website was afhankelijk van event subscriptions. | Website vraagt periodiek de volledige actuele state op. |
| Debugging liep via meerdere realtimekanalen. | Debugging kan met gewone HTTP requests en serverlogs. |
| Uitbreiding vroeg extra frontend eventfilters. | Uitbreiding gebruikt consistente `bedId` en statuspayloads. |

## Controle en Troubleshooting

### Backend bereikbaar?

```bash
curl http://localhost:3000/api/state
```

Let op: `/api/state` vereist een sessie. Voor een snelle statusupdate-test gebruik je beter:

```bash
curl -X POST http://localhost:3000/api/call \
  -H "Content-Type: application/json" \
  -d '{"room":"C302","bed":"1","status":"call"}'
```

### PM2 logs bekijken

```bash
pm2 logs
```

Zoek naar:

```text
Update ontvangen
SimLab API draait op poort 3000
```

### Home Assistant test

Voer in Home Assistant handmatig een REST command uit en controleer daarna:

- PM2 logs;
- browser dashboard;
- Network tab in DevTools;
- response van `/api/state` na login.

## Samenvatting

De productieflow is:

```text
Zigbee knop -> Home Assistant automation -> REST command -> POST /api/call -> backend state -> GET /api/state -> dashboard
```

Deze aanpak is lokaal, eenvoudig te testen, schaalbaar naar meerdere kamers en robuust genoeg voor gebruik in een schoolomgeving.

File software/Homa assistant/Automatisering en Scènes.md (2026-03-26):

# Scènes Toevoegen

We maken gebruik van scènes omdat we daarmee een vaste kleur voor de ledstrip kunnen instellen wanneer een bepaalde scène wordt geactiveerd. In een automatisering zelf kunnen we namelijk niet rechtstreeks bepalen welke kleur de ledstrip moet hebben. Dit is dus een kleine omweg om dat toch mogelijk te maken.

## Scènes aanmaken

In Home Assistant ga je naar Instellingen → Automatiseringen en scènes, en klik je vervolgens bovenaan op Scènes.
[Instelling Home assitant](/software/afbeeldingen/Instellingen%20Home%20Assistant.png)

[Automatisering en Scènes](/software/afbeeldingen/automatisering%20en%20scènes.png)

[Tablad scènes](/software/afbeeldingen/Tablad%20scènes.png)

Zodra je hier bent, kun je onderaan op Scène toevoegen klikken.
[Scène Toevoegen](/software/afbeeldingen/scène%20toevoegen.png)

Vervolgens voeg je bij Apparaten een nieuw apparaat toe en zoek je in de lijst naar het juiste apparaat. In dit geval is dat “unk_manufacturer unk_model”.

Zodra dit is gelukt, klik je op het lampje om de kleur in te stellen die je wilt gebruiken.
[Kleur instellen](/software/afbeeldingen/kleur%20instellen.png) 

Als dit gelukt is, zie je dat het lampje de kleur heeft die je hebt gekozen.
[kleur ingesteld](/software/afbeeldingen/kleur%20ingesteld.png)

Daarna hoef je de scène alleen nog op te slaan en een naam te geven naar keuze.

# Automatisering Toevoegen

Dit moet worden gedaan omdat de knop en de ESP met ledstrip twee aparte apparaten zijn en dus niet rechtstreeks met elkaar kunnen 
verbinden. Daarom wordt er gebruikgemaakt van een automatisering die bepaalt: als dit gebeurt, moet dat worden uitgevoerd.

## Automatisering maken 

In Home Assistant ga je naar Instellingen → Automatiseringen en scènes, en klik je vervolgens bovenaan op Scènes.
[Instelling Home assitant](/software/afbeeldingen/Instellingen%20Home%20Assistant.png)

[Automatisering en Scènes](/software/afbeeldingen/automatisering%20en%20scènes.png)

[Tablad automatisering](/software/afbeeldingen/Tablad%20scènes.png)

Je komt standaard op het automatiseringsblad terecht, dus druk je rechtsonder op ‘Automatisering toevoegen’.
[automatisering toevoegen](/software/afbeeldingen/automatisering%20toevoegen.png)

Op het tweede scherm klik je op ‘Automatisering toevoegen’ en daarna krijg je dit scherm te zien.

[automatisering maken](/software/afbeeldingen/automatisering%20maken.png)

Het eerste wat je doet, is een trigger aanmaken voor de knop. Klik hiervoor op ‘Trigger toevoegen’ en kies ‘Apparaat’. Daarna 
verschijnt dit scherm.

[trigger_apparaat](/software/afbeeldingen/trigger_apparaat.png)

Daarna ga je in de lijst zoeken naar het apparaat dat je wilt gebruiken voor de trigger. In ons geval is dit de eWeLink SNZB-01P. 
Selecteer dit apparaat. Vervolgens moet je de trigger kiezen; in dit geval kiezen we voor "Drukknop" knop ingedrukt. Dan moet je 
dit zien staan. 

[trigger correct](/software/afbeeldingen/trigger%20correct.png)

De volgende stap is het toevoegen van een actie. Klik op ‘Actie toevoegen’ en kies ‘Scène toevoegen’. Selecteer daarna ‘Inschakelen’. Vervolgens klik je op ‘Doel toevoegen’ en kies je de gewenste scène; in ons geval is dat ‘demo’.
 
[actie aanmaken](/software/afbeeldingen/actie%20maken.png)

Daarna hoef je enkel nog de automatisering op te slaan en een naam naar keuze te geven. Vervolgens is de automatisering klaar 
voor gebruik.

## Automatisering uitzetten(dit moet je maar doen bij 1 van de drie automatiseringen)
Nu heb je wel het probleem dat je de scène kunt aanzetten, maar nog niet kunt uitzetten. Hiervoor moet je een kleine aanpassing 
doen in je demo.
Als je meerdere scènes gebruikt die je met één drukknop inschakelt, hoef je maar één keer een uit-functie te maken om alle scènes 
die je hebt uit te schakelen.

Bij ‘Actie toevoegen’ ga je nu bovenaan naar ‘Bouwstenen’ en kies je ‘Als-dan voorwaarde’.
Bij ‘Als’ voeg je het apparaat unk_manufacturer unk_model toe en stel je in dat het uitgeschakeld is.
Daarna voeg je bij ‘Dan’ de instelling ‘Scène toevoegen’ toe en selecteer je de gewenste scène.
Vervolgens voeg je bij ‘Anders’ de actie toe om unk_manufacturer unk_model uit te zetten.

[als dan functie](/software/afbeeldingen/Als%20dan%20functie.png)

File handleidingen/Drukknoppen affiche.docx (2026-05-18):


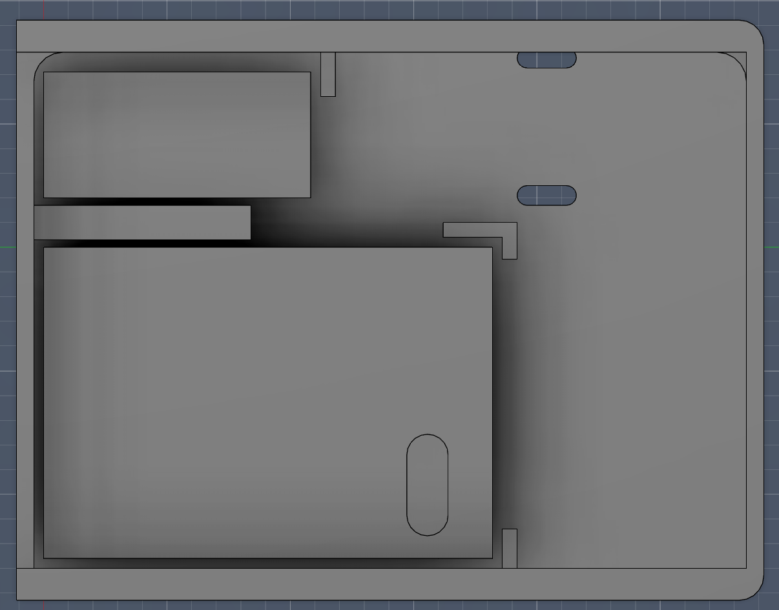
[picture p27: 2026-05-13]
hardware/afbeeldingen/AfbeeldingOV1.png

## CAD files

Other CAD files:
hardware/3D_prints/BestandenFusion360/Behuizing4_Volledig.f3z
hardware/3D_prints/BestandenFusion360/UniVerbinding.f3z

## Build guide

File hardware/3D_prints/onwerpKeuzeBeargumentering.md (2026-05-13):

# **Beargumentatie ontwerp keuzes behuizing**

# Inleiding

In dit bestand zal de argumentatie rond de keuzes die werden gemaakt voor het eind ontwerp van de behuizing terug te vinden zijn, ook de meerdere iteraties van het ontwerp worden hier besproken en waarom we bepaalde keuzes hebben gemaakt.

# Argumentatie

## Lay-out

Na veel proberen, zijn we uitgekomen bij de powerbank aan de onderzijde en de ESP32 ernaast aan de bovenzijde gepositioneerd (gezien van bovenaf). We hebben hiervoor gekozen omwille van de positionering van de knoppen en de poorten van de powerbank. Op deze manier is alles makkelijk bereikbaar en ziet de behuizing er niet lomp uit omwille van de diepte.

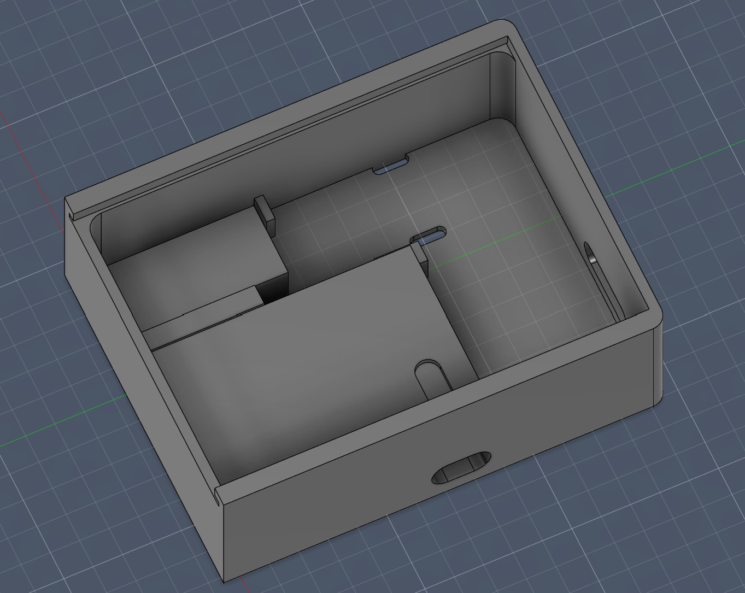
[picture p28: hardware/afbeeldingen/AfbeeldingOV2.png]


### Andere iteraties
Voordien waren er andere iteraties van de behuizing, waarbij we potentiële ontwerpen uit tekenden om de voordelen en nadelen af te wegen.
Deze worden hier besproken.

#### Versie 1
Versie 1 was meer bedoelt als startpunt voor de andere versies. Er werd een eerste 3D ontwerp getekend dat kan gebruikt worden om op verder te bouwen of als referentie.

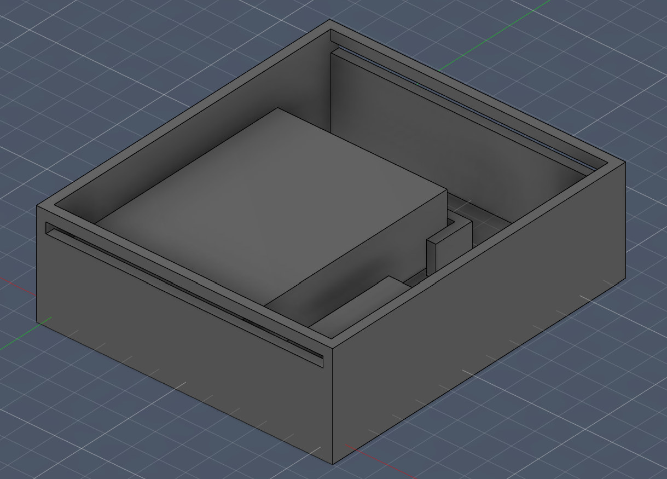
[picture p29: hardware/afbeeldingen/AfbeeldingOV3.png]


#### Versie 2
Versie 2 was een ontwerp voor het visualiseren van een concept die we hadden. Bij deze versie was de ESP32 bovenop de powerbank. Dit zou er wel voor zorgen dat de behuizing smaller is, het is dan echter wel hoger en lomper van vorm en vraagt voor een complexere structuur. Daarom hebben we hiervoor ook niet gekozen.

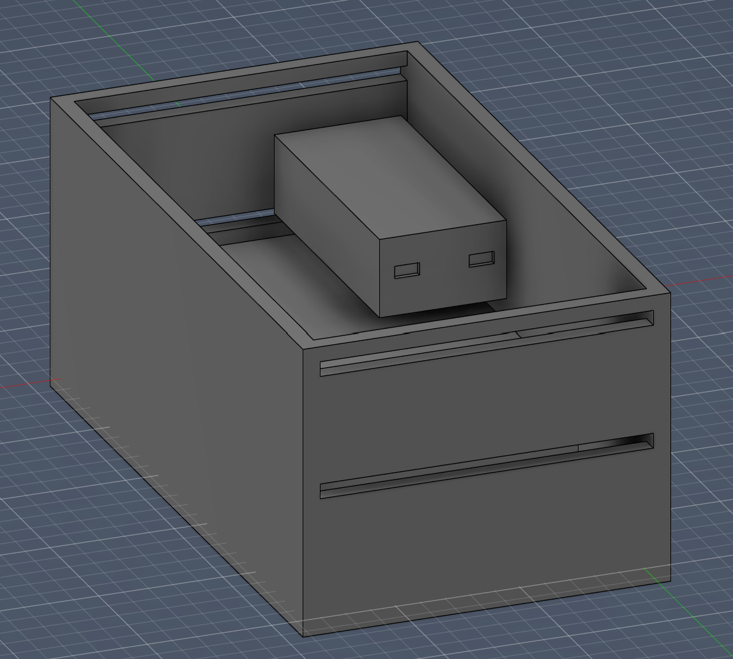
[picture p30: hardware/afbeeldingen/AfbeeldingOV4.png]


#### Versie 3
Versie 3 was de eerste versie waarvan we zeker genoeg waren om deze te 3D printen. Het ontwerp had de ESP32 boven de powerbank gelegen aan de bovenzijde gepositioneerd (gezien van bovenaf).
We zagen echter een probleem die pas heel duidelijk werd bij het 3D printen van de behuizing, de manier waarop we het deksel inschuiven en uitschuiven.
Bij het ontwerpen leek deze methode stevig en betrouwbaar, dit was echter niet volledig zo. Door het 3D printen zelf is de onderkant van de opening om het deksel door te schuiven beginnen hangen. Dit zorgt ervoor dat de opening niet groot genoeg was. Een ander nadeel is dat de dikte van het stuk boven de opening niet dik genoeg was, dit zorgde ervoor dat dit stuk makkelijk heen en weer kon geplooid worden.

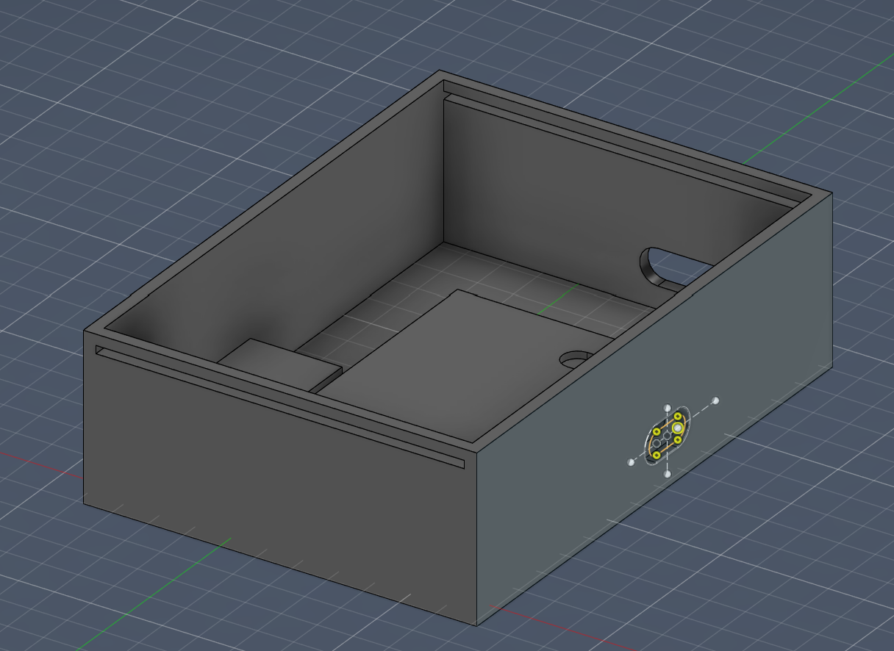
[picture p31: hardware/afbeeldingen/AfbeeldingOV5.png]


#### Versie 4
Versie 4 is het uiteindelijke ontwerp geworden. Deze versie lijkt zeer veel op versie 3 met een aantal kleine veranderingen. De grootste aanpassing is het systeem dat we gebruiken om de behuizing te openen. We hebben ook de afmetingen lichtjes verandert en een aantal voorzieningen toegevoegt.



### Belangrijke onderdelen
-	Bevat kleine binnenmuren: Dit zorgt voor het in plaats houden van de losse componenten.
-	Bevat gaten voor bereik: Dit zorgt ervoor dat de knoppen en poorten van de powerbank makkelijk bereikbaar zijn.
-	Bevat gaten voor riemen: Er zijn gaten voorzien om los liggende kabels vast te hangen met behulp van een spanband of riem.
-	Bevat ventilatiegaten: Deze gaten zijn niet heel noodzakelijk omdat de componenten niet extreem warm worden, toch worden deze gebruikt vooral voor de ESP32 omdat deze wel wat warm wordt bij langdurig gebruik.
-	Bevat schuifgleuven: Dit wordt gebruikt om het deksel in te schuiven.
-	Bevat afrondingen om de LED strip makkelijker te bevestigen.

## Toegang poorten en knoppen

We hielden er telkens rekening mee dat de interne componenten vlot bereikbaar moeten zijn.

We zorgden er voor dat er openingen voorzien zijn om de power knop van de powerbank in te kunnen drukken en zodat de oplaad poort van de powerbank naar buiten kan gebracht worden, op deze manier moet de behuizing niet geopend worden om het op te laden.

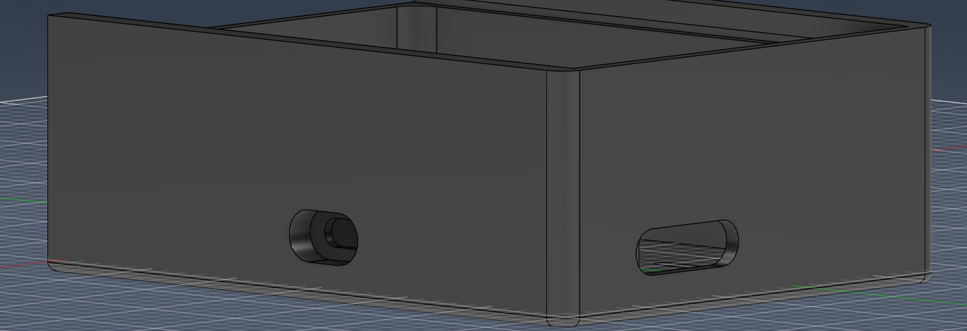
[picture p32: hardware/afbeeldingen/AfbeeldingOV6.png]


## LED strip

De LED strip wordt aan de binnenkant van de behuizing bevestigd. Door een melk plectieplaat te gebruiken als deksel, zullen de LED’s goed zichtbaar zijn. Er zijn dan ook gleuven voorzien om deze plaat door te schuiven.

Door de aanwezigheid van een afronding in de hoeken, is de LED strip niet geplooid als deze geplakt wordt.

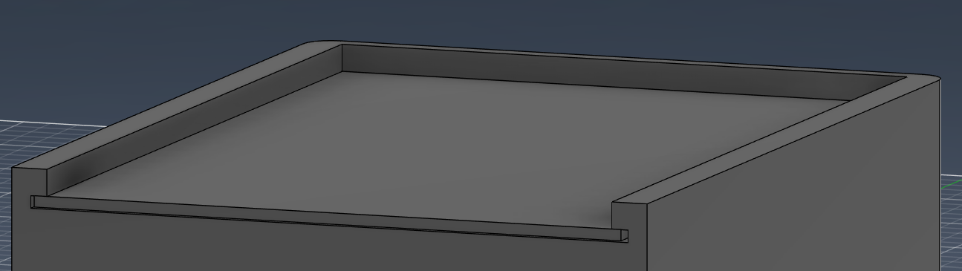
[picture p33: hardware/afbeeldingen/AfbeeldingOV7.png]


## Zichtbaarheid licht

Omdat de LED strip aan de binnenkant van de behuizing zit, moeten we ervoor zorgen dat alles goed zichtbaar is naar buiten toe. Op het eerste zicht ziet alles er duidelijk uit, door het gebruik van een witte PLA en de goede hangplaats van de LED strip kaatst het licht genoeg rond. Het licht is fel genoeg om van ver duidelijk het kleur te zien. Ook al is de zichtbaarheid goed, gebruiken we toch een reflecterende rol zodat het licht nog extra goed kan rondkaatsen. Dit helpt ook met het even belichten van het deksel, zodat er zeker geen donkere plekken meer zichtbaar zijn.

## Ventilatiegaten

Onder de powerbank en ESP32 zijn er ook ventilatiegaten voorzien, deze hebben als functie de componenten op een veilige en functionele temperatuur te houden.

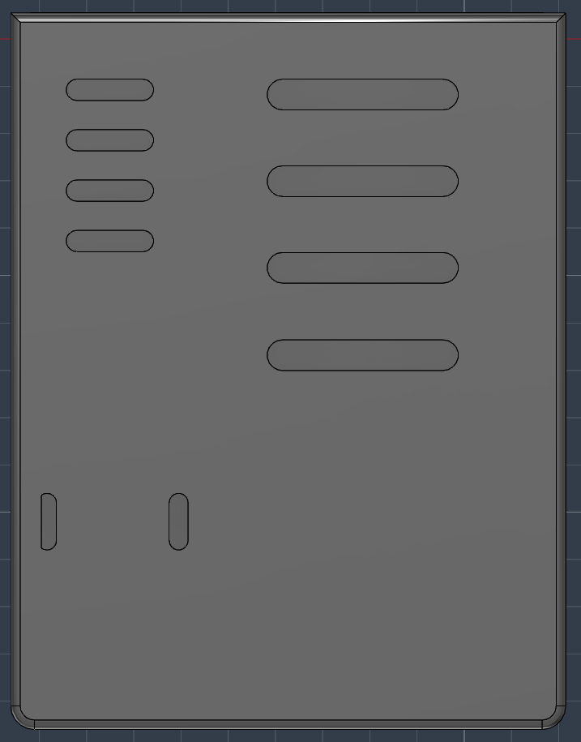
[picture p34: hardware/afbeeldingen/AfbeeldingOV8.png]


### Gaten powerbank

De temperatuur van de powerbank blijft ook bij langdurig gebruik laag, toch kiezen we ervoor om deze gaten te voorzien. De gaten kunnen ook de temperatuur van de LED's en de totale behuizing verlagen.

### Gaten ESP32

De temperatuur van de ESP32 kan wel relatief warm worden, vandaar dat we de gaten voorzien.

## Deksel

### Maken deksel
Voor het deksel wordt een plaat met dikte 2 mm gelazercut met afmetingen volgens het gat van de behuizing.

### Bevestigen deksel
Als bevestiging van het deksel gebruiken we een schuifsysteem. Hierdoor kan de behuizing makkelijk geopend worden mocht dit nodig zijn.

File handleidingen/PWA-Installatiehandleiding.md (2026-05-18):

# PWA Installatiehandleiding

## Inhoudstafel
[**Inleiding**](#inleiding)<br>
[**Installatie op iPhone (Safari)**](#installatie-op-iphone-safari)<br>
[**Installatie op Android (Google Chrome)**](#installatie-op-android-google-chrome)<br>

---

## Inleiding
Deze handleiding legt uit hoe je de applicatie als PWA (Progressive Web App) installeert op je smartphone. Een PWA gedraagt zich als een gewone app maar wordt rechtstreeks via de browser geïnstalleerd, zonder gebruik te maken van de App Store of Google Play Store.

Volg de stappen hieronder voor jouw toestel.

---

## Installatie op iPhone (Safari)

> **Let op:** gebruik verplicht de **Safari**-browser op iPhone. Andere browsers (Chrome, Firefox, …) ondersteunen de installatie niet op iOS.

### Stap 1 — Open Safari en surf naar de link

Ga naar [https://verpleegkunde.voltlab.net/](https://verpleegkunde.voltlab.net/) in Safari.

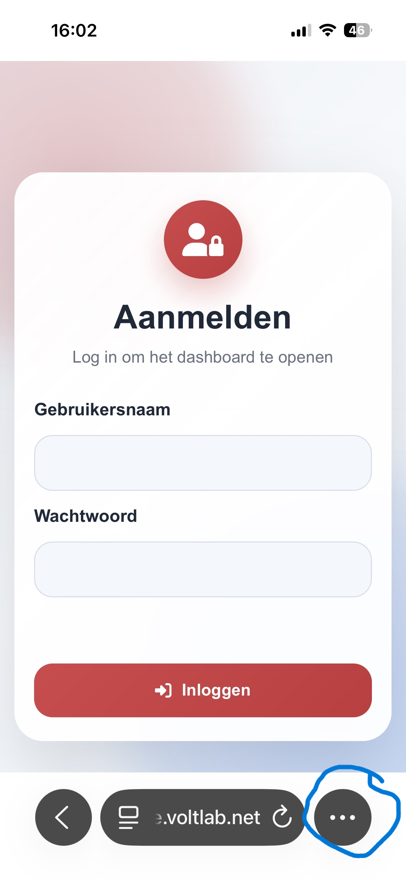
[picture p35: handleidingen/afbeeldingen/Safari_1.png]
Stap 1 – Open de website in Safari


---

### Stap 2 — Tik op de 3 bolletjes

Tik rechts onderaan (of bovenaan) in Safari op de **3 bolletjes** om het menu te openen.

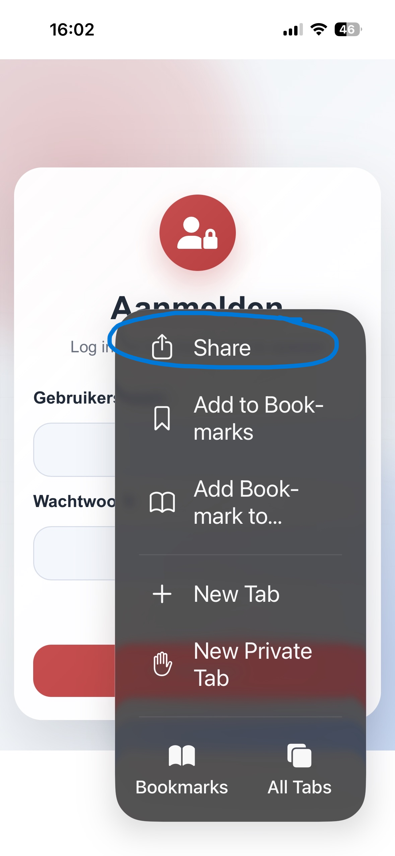
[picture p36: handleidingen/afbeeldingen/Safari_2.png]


---

### Stap 3 — Tik op "Delen" (Share)

Tik in het menu op **Delen** (Share).

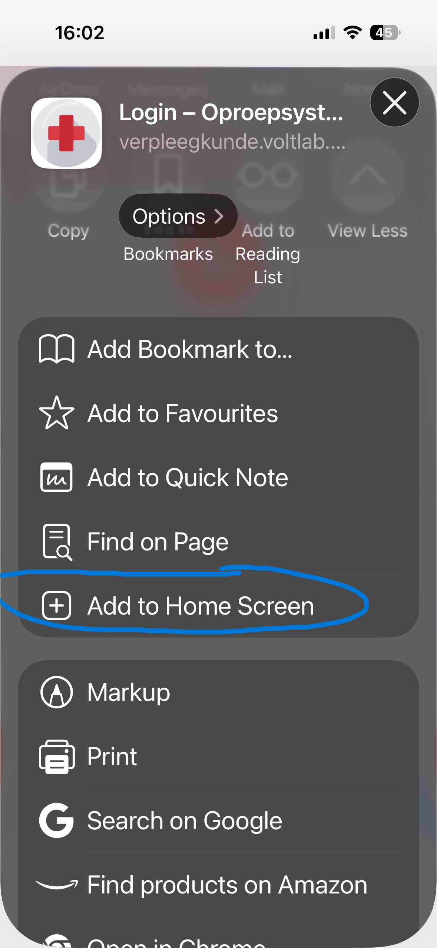
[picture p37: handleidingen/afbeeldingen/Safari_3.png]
Stap 3 – Deel-optie


---

### Stap 4 — Tik op "Zet op beginscherm" (Add to Home Screen)

Scroll in het deelmenu naar beneden en tik op **Zet op beginscherm** (Add to Home Screen).

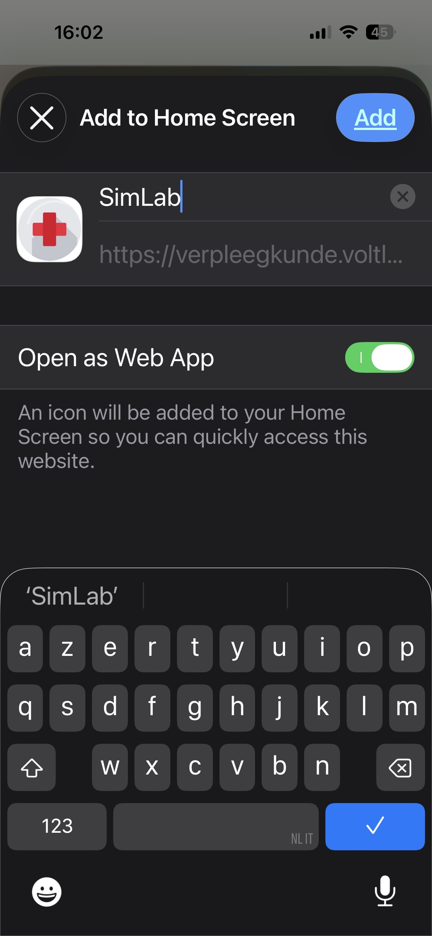
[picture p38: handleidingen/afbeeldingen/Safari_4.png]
Stap 4 – Toevoegen aan beginscherm


---

### Stap 5 — Zet "Open as Web App" aan en geef een naam

Zet de optie **Open as Web App** aan en geef de app een naam naar keuze.

---

### Stap 6 — Tik op "Voeg toe" (Add)

Bevestig door op **Voeg toe** (Add) te tikken. De app verschijnt nu op je beginscherm.

---

## Installatie op Android (Google Chrome)

> **Let op:** gebruik verplicht de **Google Chrome**-browser op Android voor de installatie.

### Stap 1 — Open Chrome en surf naar de link

Ga naar [https://verpleegkunde.voltlab.net/](https://verpleegkunde.voltlab.net/) in Google Chrome.

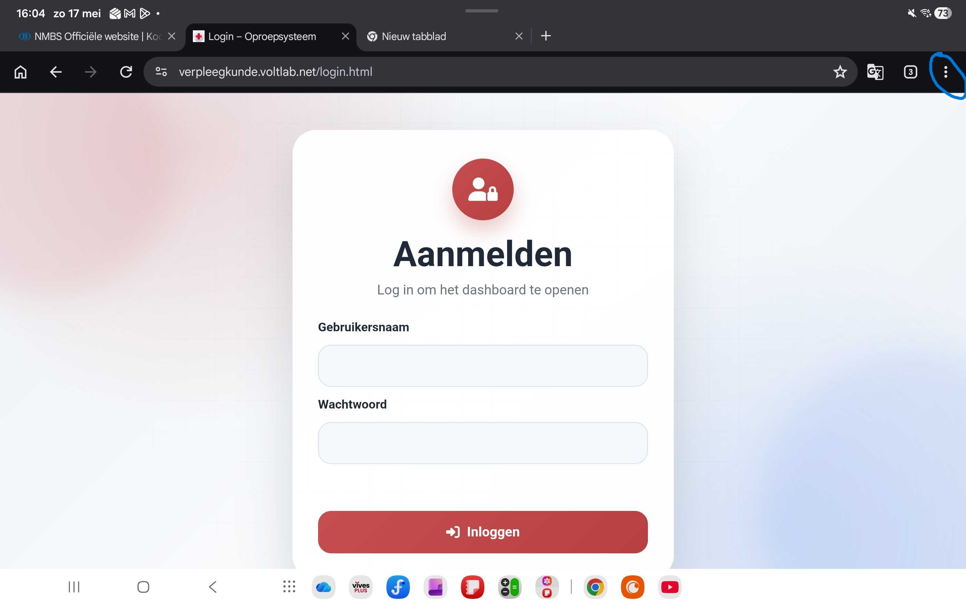
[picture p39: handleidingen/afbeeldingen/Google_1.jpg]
Stap 1 – Open de website in Chrome


---

### Stap 2 — Tik op de 3 bolletjes

Tik rechtsboven op de **3 bolletjes** om het menu te openen.

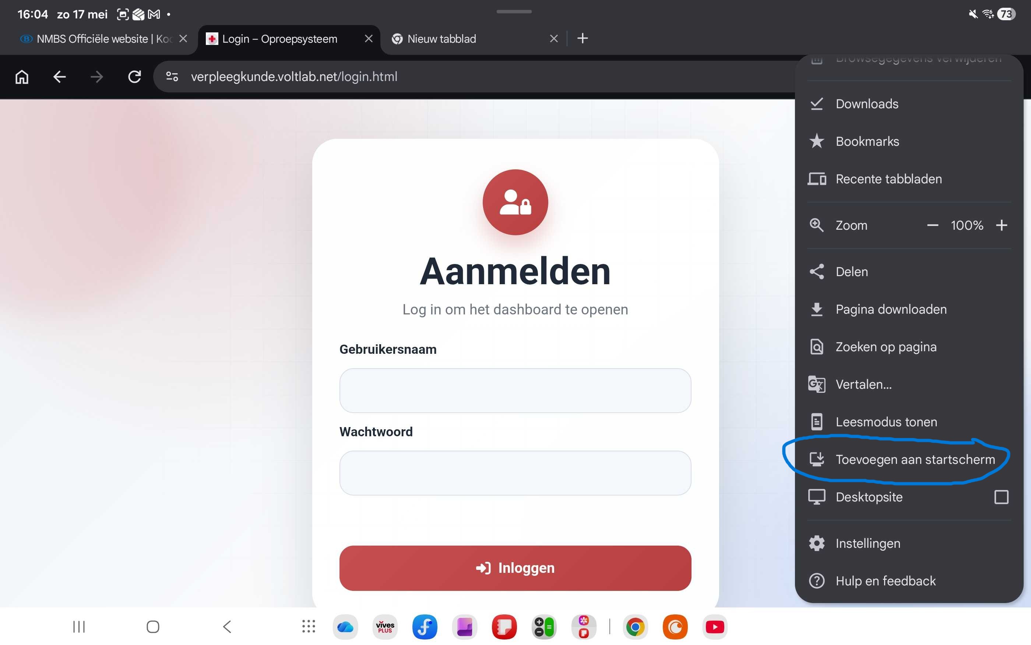
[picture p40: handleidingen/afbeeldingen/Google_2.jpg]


---

### Stap 3 — Tik op "Toevoegen aan startscherm" (Add to Home Screen)

Tik in het menu op **Toevoegen aan startscherm** (Add to Home Screen).

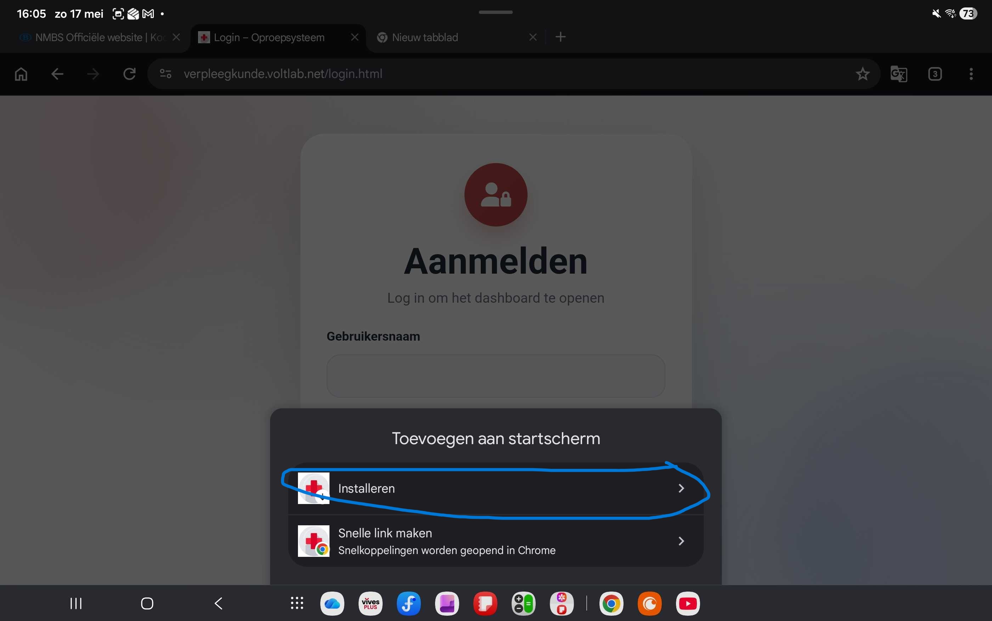
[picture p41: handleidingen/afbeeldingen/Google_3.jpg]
Stap 3 – Toevoegen aan startscherm


---

### Stap 4 — Tik op "Installeren"

Bevestig door op **Installeren** te tikken. De app verschijnt nu op je startscherm.

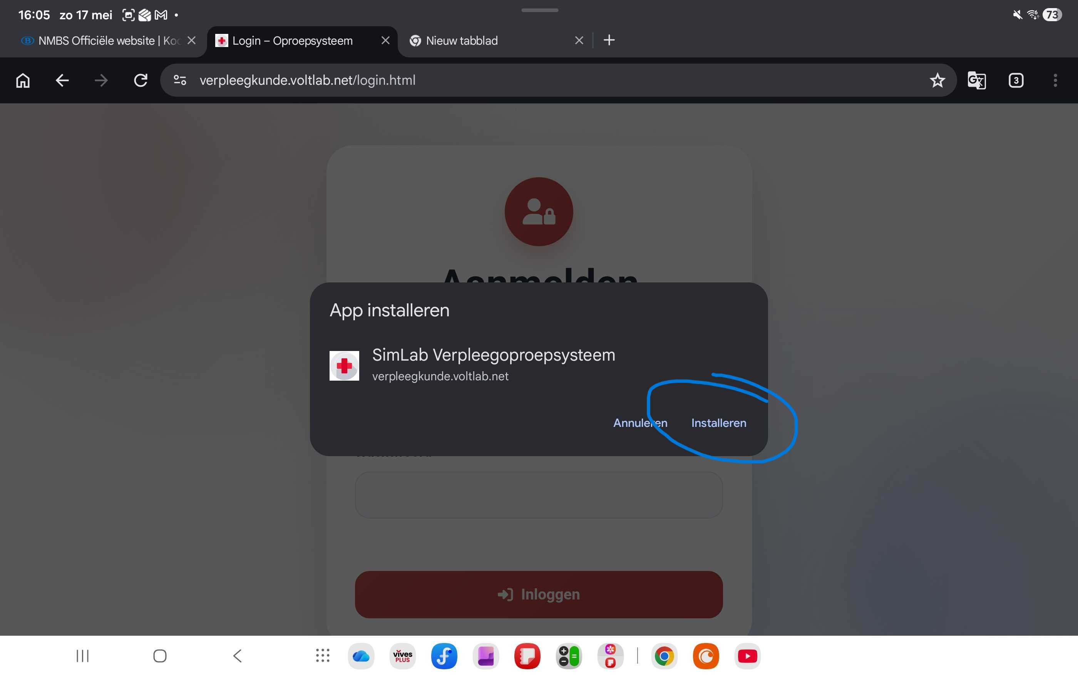
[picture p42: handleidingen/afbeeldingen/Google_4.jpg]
Stap 4 – Installeren


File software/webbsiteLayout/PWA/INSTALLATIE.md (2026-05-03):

# Installatie Website en PWA

Deze installatie gaat alleen over de webapp.

## Backend starten

```bash
cd backend
npm install
copy ..\.env.example .env
npm start
```

Open daarna:

```text
http://localhost:3000
```

## Standaard login

Gebruik lokaal de voorbeeldgebruikers uit `server.js`:

```text
Leerkracht / Leerkracht1
Leerling / Leerling1
```

Voor productie plaats je echte gegevens in `backend/users.json`. Commit dat bestand niet.

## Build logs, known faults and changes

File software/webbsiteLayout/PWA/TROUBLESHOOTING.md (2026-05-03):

# Troubleshooting Website en PWA

## Login werkt niet

- Controleer of de server draait.
- Controleer `backend/users.json` of de standaardlogin.
- Kijk in de browserconsole of `/api/login` een fout geeft.

## Dashboard blijft leeg

Test:

```bash
curl http://localhost:3000/api/state
```

Let op: deze route vraagt een sessie. In de browser moet je eerst ingelogd zijn.

## Push notifications werken niet

- Controleer of HTTPS actief is in productie.
- Controleer `VAPID_PUBLIC_KEY` en `VAPID_PRIVATE_KEY` in `.env`.
- Controleer of de browser notificaties toestaat.
- Controleer of `sw.js` bereikbaar is via `/sw.js`.

## Oude versie blijft zichtbaar

- Hard refresh: `Ctrl + Shift + R`.
- Verwijder de service worker via DevTools.
- Verhoog eventueel `CACHE_NAME` in `frontend/sw.js`.

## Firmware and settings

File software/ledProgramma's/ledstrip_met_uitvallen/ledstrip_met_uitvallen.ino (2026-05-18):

#ifndef ZIGBEE_MODE_ED
#error "Zigbee end device mode is not selected in Tools->Zigbee mode"
#endif

#include "Zigbee.h"
#include <Adafruit_NeoPixel.h>
#include "esp_sleep.h"

/* Zigbee light bulb configuration */
#define ZIGBEE_LIGHT_ENDPOINT 10

#define LED_PIN 2
#define NUM_LEDS 12
Adafruit_NeoPixel strip(NUM_LEDS, LED_PIN, NEO_GRB + NEO_KHZ800);

uint8_t button = BOOT_PIN;

unsigned long lastActivityTime = 0;
const unsigned long sleepTimeout = 3600000; // 1h

// We gebruiken hier nu ZigbeeColorDimmableLight ipv ZigbeeLight
ZigbeeColorDimmableLight zbLight = ZigbeeColorDimmableLight(ZIGBEE_LIGHT_ENDPOINT);

/********************* RGB LED functions **************************/
// Callback voor als Home Assistant een nieuwe commando (kleur/helderheid/status) doorstuurt
void setLightAndColor(bool state, uint8_t red, uint8_t green, uint8_t blue, uint8_t level) {
  lastActivityTime = millis();

  if (state) {
    // Stel we gebruiken brightless/level
    strip.setBrightness(level);
    for(int i=0; i<strip.numPixels(); i++) {
        strip.setPixelColor(i, strip.Color(red, green, blue));
    }
  } else {
    // Zet alle LEDs uit
    strip.clear();
  }
  strip.show();
}

/********************* Arduino functions **************************/
void setup() {
  Serial.begin(115200);

  // Init LED strip
  strip.begin();
  strip.show();

  // Init button for factory reset
  pinMode(button, INPUT_PULLUP);

  //Optional: set Zigbee device name and model
  //zbLight.setManufacturerAndModel("Espressif", "Ledstrip");

  // Set callback function for light and color change
  zbLight.onLightChange(setLightAndColor);

  //Add endpoint to Zigbee Core
  Serial.println("Adding ZigbeeLight endpoint to Zigbee Core");
  Zigbee.addEndpoint(&zbLight);

  // When all EPs are registered, start Zigbee. By default acts as ZIGBEE_END_DEVICE
  if (!Zigbee.begin()) {
    Serial.println("Zigbee failed to start!");
    Serial.println("Rebooting...");
    ESP.restart();
  }

  Serial.println("Connecting to network");
  while (!Zigbee.connected()) {
    Serial.print(".");
    delay(100);
  }
  Serial.println();

  // Zigbee is verbonden: 3 seconden groen
  strip.setBrightness(100);
  for (int i = 0; i < strip.numPixels(); i++) {
    strip.setPixelColor(i, strip.Color(0, 255, 0));
  }
  strip.show();
  delay(3000);
  strip.clear();
  strip.show();

  lastActivityTime = millis();
}

void loop() {
  // Checking button for factory reset
  if (digitalRead(button) == LOW) {  // Push button pressed
    // Key debounce handling
    delay(100);
    lastActivityTime = millis();

    int startTime = millis();
    while (digitalRead(button) == LOW) {
      delay(50);
      if ((millis() - startTime) > 3000) {
        // If key pressed for more than 3secs, factory reset Zigbee and reboot
        Serial.println("Resetting Zigbee to factory and rebooting in 1s.");
        delay(1000);
        Zigbee.factoryReset();
      }
    }
    // Toggle light by pressing the button
    zbLight.setLightState(!zbLight.getLightState());
  }

  if (millis() - lastActivityTime > sleepTimeout) {
    Serial.println("No activity for 1 h. Going to deep sleep.");

    strip.clear();
    strip.show();

    delay(100);

    esp_deep_sleep_start();
  }

  delay(100);
}

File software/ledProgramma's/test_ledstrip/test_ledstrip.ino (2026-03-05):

#include <Adafruit_NeoPixel.h>

#define LED_PIN     2
#define LED_COUNT   6

Adafruit_NeoPixel strip(LED_COUNT, LED_PIN, NEO_GRB + NEO_KHZ800);

void setup()
{
  strip.begin();
  strip.show();
}

void loop()
{
  colorWipe(strip.Color(255, 0, 0), 400);
  colorWipe(strip.Color(0, 255, 0), 400);
  colorWipe(strip.Color(0, 0, 255), 400);
}

void colorWipe(uint32_t color, int wait)
{
  for (int i = 0; i < strip.numPixels(); i++)
  {
    strip.setPixelColor(i, color);
    strip.show();
    delay(wait);
  }
}

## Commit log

2026-02-18 Handleiding installatie homeassistant op raspberry pi toegevoegd met afbeeldingen.
2026-02-26 Informatie LED strip
2026-03-05 final
    # SimLab Verpleegkunde Oproepsysteem
    Een slim oproepsysteem voor ziekenhuiskamers met real-time status monitoring via een webdashboard.
    ## Features
    - 🏥 Real-time kamer status dashboard
    - 🔴 Hulp gevraagd melding (korte klik)
    - 🟠 Collega aanwezig status (lange klik)
    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
2026-03-05 website.md
    Update: documentatie is nu inhoudelijk bijgewerkt op basis van jullie echte flow. Ik controleer nog kort alle aangepaste bestanden zodat alles consistent is voor commit/push.
    Ik heb het toegevoegd en de repo bijgewerkt naar de huidige werking.
    Wat is aangepast
    Documentatie herschreven met jullie echte communicatieflow in software/Home assistant website.md.
    Realtime communicatie README geactualiseerd in README.md.
    Hardcoded long-lived token verwijderd uit index.html.
    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
2026-03-12 Aanapssing Code
    Dit is de werkende code en kan hier terug naar gepulled worden bij fouten
2026-04-01 EINDELIJK,
    Server -> HA -> DNS WEBSITE werkt
    [Behuizing_ESP_LED_POWERBANK.blend]
2026-04-10 Kleine aanpasingen mappen structuur.
    [Behuizing_ESP_LED_POWERBANK.blend]
2026-04-10 Aanpassingen ontwerpkeuze van de behuizing, nog geen foto's toegevoegd totdat we zeker zijn.
    [Behuizing4Volledig.f3z]
2026-04-27 Powerbank gegevens toegevoegd en levensduur beargumenteerd.
2026-05-01 Toevoegingen GebruikersHandleiding en aanpassingen aan hardware powerbank.
2026-05-03 Documetnatie PWA/ Website Layout
    Website en PWA voor het SimLab verpleegoproepsysteem met dashboard, login, API-backend en push notifications.
2026-05-07 Update README PWM
    Aanpassing:
    Echte voorbeeld codes ipv oude "demo"
2026-05-07 Nieuwe print bestanden toegevoegd.
    [Behuizing4Volledig.f3z, UniVerbinding.f3z]
2026-05-09 naam van het document aangepast
2026-05-14 Raspberry Pi 5 configuratie toegevoegd
2026-05-14 Document voor netwerk van de pi aangemaakt + al wat tekst geschreven
2026-05-15 Bestand toegevoegd.
    [Behuizing4_Volledig.f3z]
2026-05-18 ledstrip code met automatisch uitgaan toegevoegd
2026-05-18 Update Volledige handleiding.md
    kamer toeveogen. bed toevoegen code website
2026-05-18 documentatie voor Ledstrip_met_uitvallen toegevoegd
2026-05-18 Drukknoppen affiche toegevoegd voor printvriendelijkheid.
2026-05-18 kort uitlegbestand aangemaakt voor ledstrip.ino
